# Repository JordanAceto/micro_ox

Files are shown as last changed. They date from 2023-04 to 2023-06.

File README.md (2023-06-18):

# Analog monosynth with digital control path

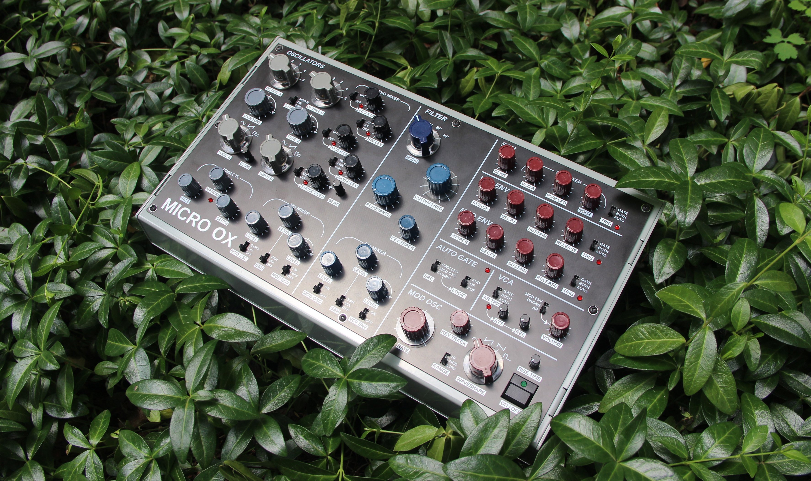
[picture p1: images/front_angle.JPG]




## The idea:
- A stripped down version of the [Josh Oxford Ribbon Synth](https://github.com/JordanAceto/josh_Ox_ribbon_synth) with some changes
- No integrated ribbon controller
- MIDI and CV inputs

## Status:
- 1st prototype is built and under evaluation
- All major features work
- There are a few PCB kludges required for the first board revisions
- Expect minor componenent and code changes as evalutation continues
- The jack panel and body are not started yet
- Documentation is incomplete while the design is in flux, expect some dead links to schematics/etc for now

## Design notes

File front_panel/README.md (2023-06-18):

# front_panel

## micro_ox_front_panel

PCB front
PCB back

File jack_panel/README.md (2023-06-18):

# jack_panel

## jack_panel

PCB front
PCB back

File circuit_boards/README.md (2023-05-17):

# Micro-Ox Circuit Boards

## The system is made up of a few independent PCBs

- VCO board
- VCF/VCA board
- Modulation board
- Power supply and input-output jack board

### These boards are connected to each other via IDC headers
- IDC header pinouts are chosen so it is impossible to plug them in wrong

---

## Each major system component has its own subdirectory with:
- All files needed to edit the schematic and PCB layout with KiCad
- Documentation files needed to build and troubleshoot the circuits

---

## The approximate current draw of the circuitboards is:

| Board | +12V  | -12V  |
| --- | ----- | ----- |
| main VCO  | 70mA  | 60mA  |
| VCF/VCA | 40mA  | 40mA  |
| mod board | 50mA  | 20mA  |
| | | |
| **TOTAL** | 160mA | 120mA |

---

## Some boards may need kludges (small trace cuts/fixes)
- look for a `pcb_kludges` subdirectory in a given circuitboard directory
- if this subdirectory exists, it will include instructions for the kludge in the form of a README file
- if you don't find this directory, assume that the PCB does not require any kludges

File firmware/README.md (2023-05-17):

# Rust Language STM32L412KBU Synthesizer Firmware

## Features
- MIDI receiver listens for MIDI messages via UART
- front panel potentiometers and switches are read by the microcontroller via MUX
- ADSR envelopes are generated digitally
- the Sample & Hold signal is digitized
- White Noise is generated via the built in stm32 hardware RNG and output via PWM
- external DACs generate analog voltages to control various system parameters
- LEDs driven via shift register show the state of the envelope and S&H triggers

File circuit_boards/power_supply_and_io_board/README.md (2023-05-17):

# Micro-Ox Power-Supply and IO board

## [SCHEMATIC](https://github.com/JordanAceto/micro_ox/blob/main/circuit_boards/power_supply_and_io_board/docs/power_supply_and_io_board_schematic.pdf)

Linear +/-12 volt DC power supply and input/output jacks




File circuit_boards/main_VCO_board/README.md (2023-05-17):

# Micro-Ox Dual SSI2130 VCO Board

## [SCHEMATIC](https://github.com/JordanAceto/micro_ox/blob/main/circuit_boards/main_VCO_board/docs/main_VCO_board_schematic.pdf)

## Features
- each VCO has sine, triangle, sawtooth, and variable pulse outputs
- octave switches and fine tuners
- suboctave with sawtooth and variable pulse waves
    - derived from VCO A
    - suboctave is not phase locked to VCO A, has variable beat frequency control
- flexible sync mode
    - VCO B may be soft-synced to VCO A
    - the `MOD B` setting turns off modulation to VCO A, so that only the synced VCO B is modulated
- audio mixer
- transformer/diode based ring modulator
    - XX mode multiplies VCO A with VCO B
    - XY mode multiplies VCO A with the MOD OSC
- PWM control generator
    - PWM control is clamped so the pulse waves can't go beyond about 5% and 95%
    - if overdriving the pulse waves is desired two diodes may be easily removed




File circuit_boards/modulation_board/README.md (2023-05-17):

# Micro-Ox Modulation Board

## [SCHEMATIC](https://github.com/JordanAceto/micro_ox/blob/main/circuit_boards/modulation_board/docs/modulation_board_schematic.pdf)

## Features
- MIDI input listens for a variety of MIDI messages
    - note on/off
    - pitch bend
    - mod-wheel controls the amplitude of the MOD OSC
    - VCF frequency and VCF Q messages
    - master volume
    - more MIDI control may be added in the future (velocity, portamento, sustain, etc)
- Analog Modulation Oscillator
    - SSI2130 based design with good tracking
    - low, medium, and high frequency ranges for LFO and audio rate FM
    - variable key-tracking to follow the MIDI pitch control
    - sine, up-saw, down-saw, and 50% square waves available
    - on/off switch with variable rise/fall time
- two full ADSR envelopes
    - one dedicated to the VCF
    - MOD ENV for modulation purposes
- one AR envelope for the VCA
    - the VCA may be controlled by the dedicated AR, the MOD ENV, or set to drone mode
- sample & hold
    - glide control
    - 3 input mixer
    - s&h mixer output, for use as an auxilliary modulation bus
- flexible auto gate
    - choose either the PWM LFO (from the VCO board), MOD OSC, or a combination of the two as the auto gate source
    - in combination mode the PWM LFO and MOD OSC may be combined via logical operators AND, OR, and XOR
- flexible trigger control for envelopes and sample & hold
    - each component may be triggered by MIDI, external gate signals, the auto gate, or a logical combination




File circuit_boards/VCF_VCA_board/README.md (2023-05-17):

# Micro-Ox VCF/VCA Board

## [SCHEMATIC](https://github.com/JordanAceto/micro_ox/blob/main/circuit_boards/VCF_VCA_board/docs/VCF_VCA_board_schematic.pdf)

## Features
- SSI2140 pole-mixing filter with four outputs
    - 24dB/octave lowpass
    - 12dB/octave lowpass
    - 6dB/octave bandpass
    - 18dB/octave highpass
    - other filter responses are available by changing resistor weights
- Two linear SSI2164 VCAs
    - One dedicated to the envelope
    - One dedicated to the master volume




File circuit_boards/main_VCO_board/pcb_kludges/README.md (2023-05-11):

# VCO Board PCB Kludges

The VCO board needs a kludge to scale and clamp the PWM control voltage for the SSI2130 VCOs, and a kludge to add opamp buffers to the octave switches.

## PWM Scaler Kludge

The PWM circuit on the VCO board is intended to clamp the pulse width modulation so that the width of the pulse wave can get very close to 0% and 100%, but not quite reach. This is to prevent the pulse wave from disappearing when the PWM is overdriven.

The existing clamper circuit clamps the PWM control signal to about [-5.5v, +5.5v]. This is fine for the suboctave pulse wave. But the main VCO A and VCO B pulse waves have a PWM port that is sensitive over [0v, +2.5v], and so it should be clamped to just inside this range.

The network shown below can be kludged in between the PWM output and the SSI2130 PWM input control ports.

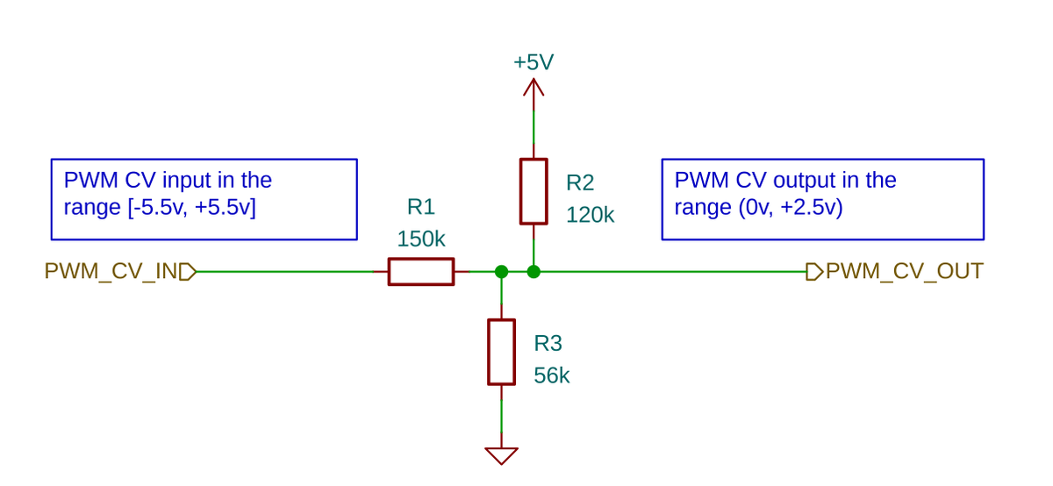
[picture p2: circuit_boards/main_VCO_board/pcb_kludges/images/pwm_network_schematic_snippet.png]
PWM network schematic snippet


This network should be installed so that the Suboctave PWM input still gets the full `[-5.5v, +5.5v]` range. 

A convenient spot to install the kludge is shown below. The input to the network is the trace coming out of the top of `D602`, and the output is the trace exiting the junction of the three kludged resistors.

- The trace going northwards from `D602` is carefully cut underneath the 150k ohm 0805 resistor, and the soldermask is carefully scraped away so that the 150k resistor can be soldered to it. 
- A small section of the soldermask covering the ground plane is scraped away so that the 56k ohm 0805 resistor can be soldered to ground.
- The 120k ohm through-hole resistor is wired to the left end of `D602`, which is connected to the +5v rail.

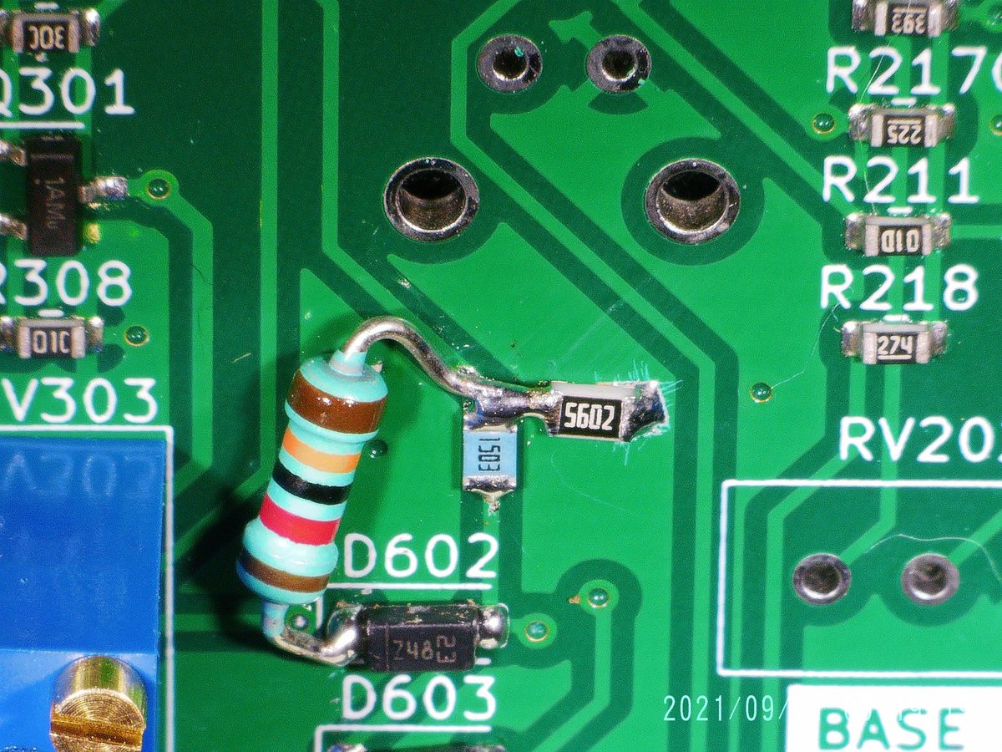
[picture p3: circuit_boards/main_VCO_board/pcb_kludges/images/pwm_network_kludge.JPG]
PWM network image


---

## Octave Switch Buffer Kludge

A single supply, rail-to-rail opamp can be installed "dead bug" style to act as a buffer between the octave switch common pins and the trimmer resistor for calibrating the octave switches. This allows the octave switches to be calibrated.

The PCB traces going from the octave switch common pins must be carefully severed with an exacto knife.

The MCP6002 or similar opamp is powered by the +5v rail. This can be accessed on the left side of R329. The minus supply pin for the opamp may be soldered to the ground plane after scraping away some solder mask.

The buffer may then be constructed according to the images and schematic snippet below.

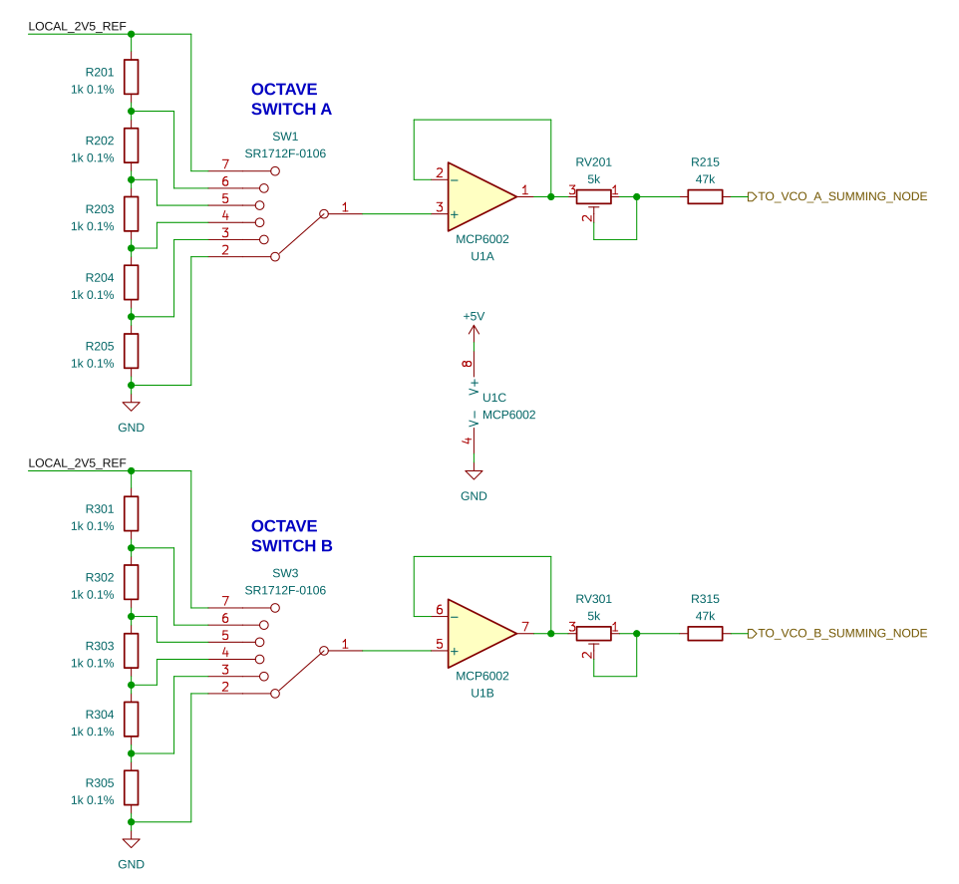
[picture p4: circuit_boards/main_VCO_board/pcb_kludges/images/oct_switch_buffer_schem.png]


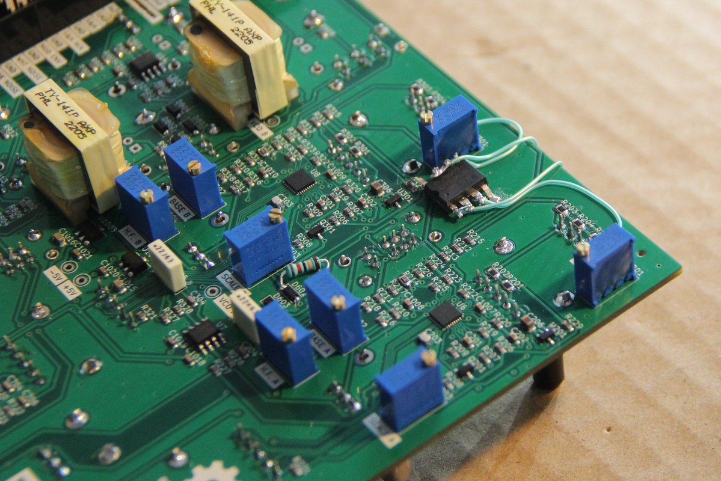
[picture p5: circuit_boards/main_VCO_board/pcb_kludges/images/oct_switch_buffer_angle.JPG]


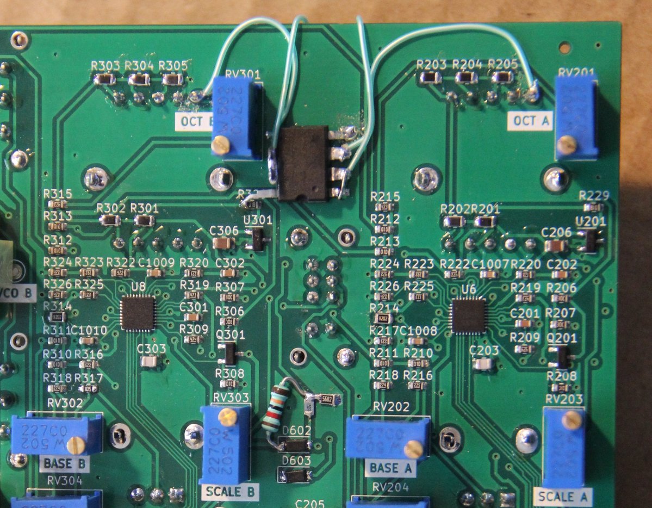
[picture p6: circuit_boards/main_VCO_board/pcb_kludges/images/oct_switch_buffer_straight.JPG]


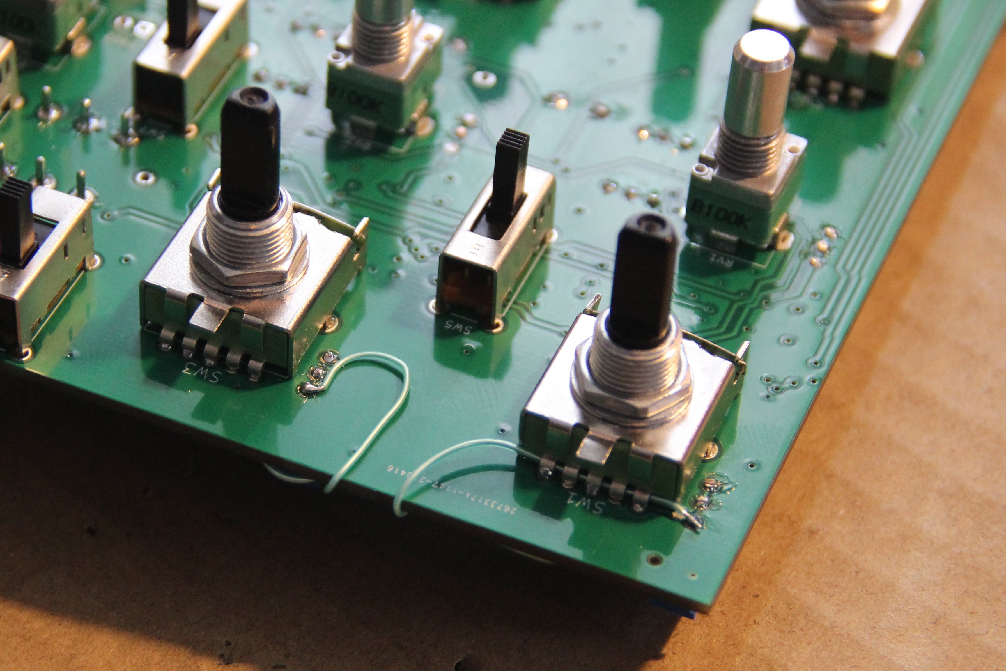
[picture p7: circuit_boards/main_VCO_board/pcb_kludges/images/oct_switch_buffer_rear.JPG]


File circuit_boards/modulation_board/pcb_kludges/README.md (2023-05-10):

# Modulation Board PCB Kludges

The modulation board needs a kludge to ensure that the MODOSC frequency range switch does not short out the +/-5 volt power suppy rails, and a kludge to bias the pink noise.

## MODOSC frequency range switch kludge

### Step 1: cut two traces

In the vicinity of the MODOSC circuitry, carefully cut the two traces as shown with an exacto knife.

The trace on the left in the image supplies -5 volts DC to the MODOOSC frequency range switch, and the trace on the right supplies +5v.

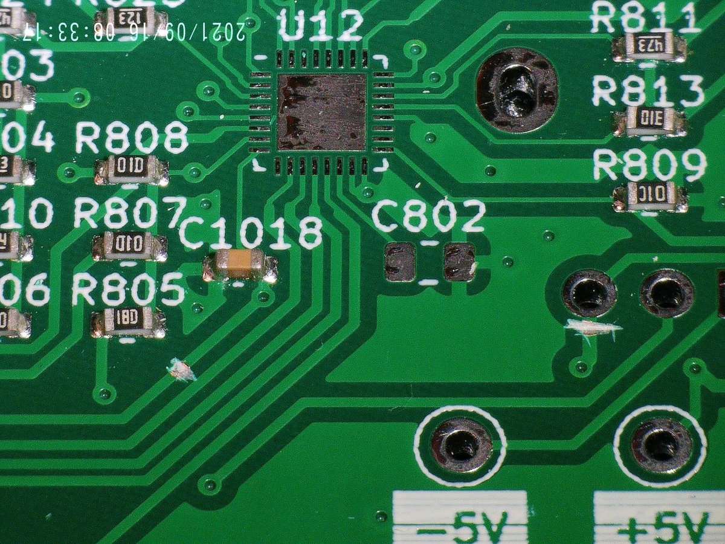
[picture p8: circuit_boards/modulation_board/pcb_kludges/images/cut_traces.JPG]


### Step 2: scrape away solder mask

With the traces severed, carefully scrape away some soldermask to provide for a surface to solder to.

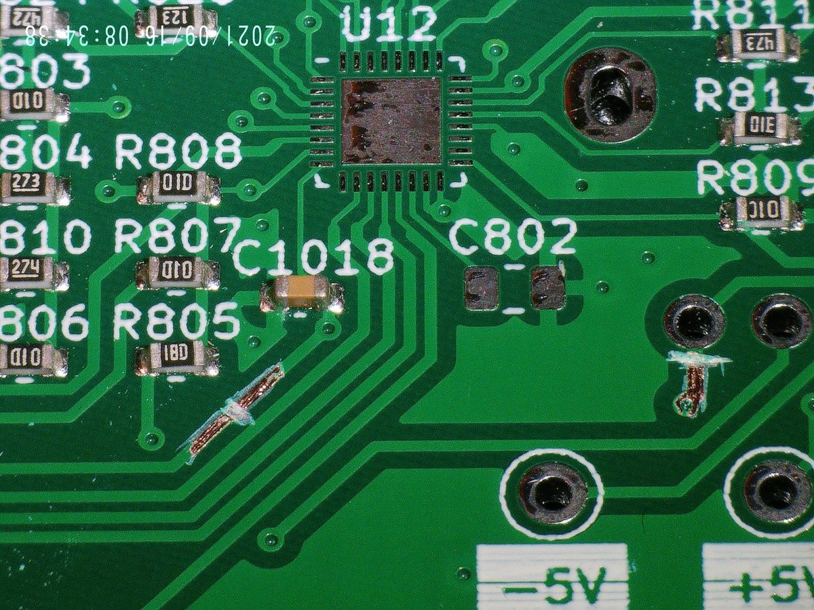
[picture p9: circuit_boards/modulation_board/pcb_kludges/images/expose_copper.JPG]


### Step 3: install two 51k ohm resistors

Solder 51k ohm resistors in series with the cut traces. This puts some impedance in series with the +/-5v lines, so even if the switch momentarily short out no drama will ensue.

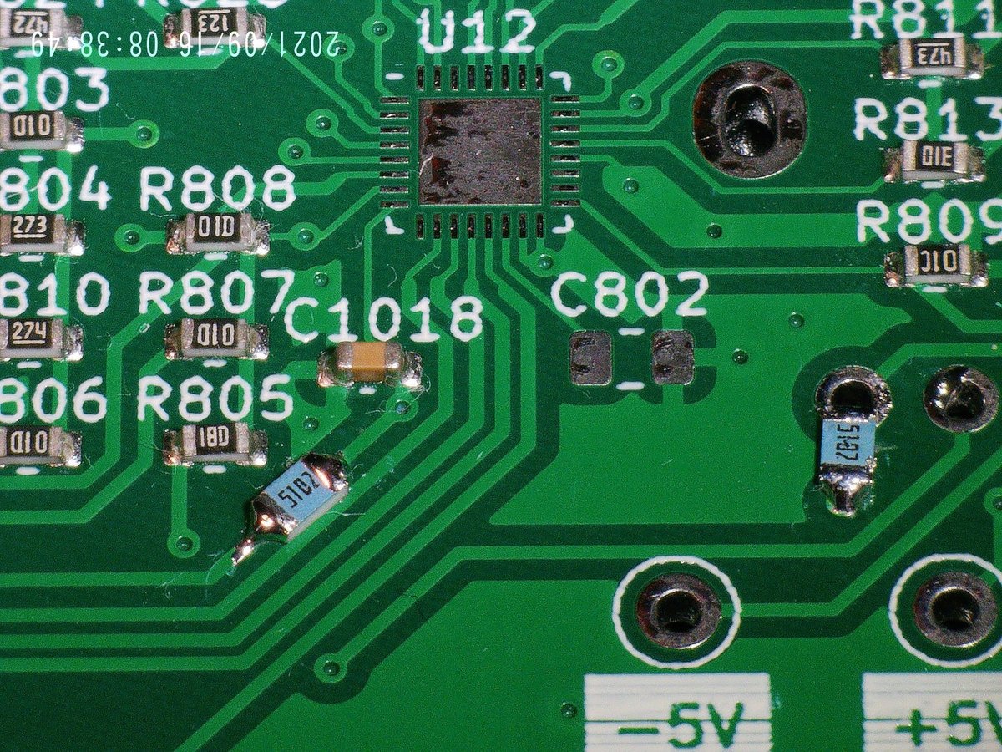
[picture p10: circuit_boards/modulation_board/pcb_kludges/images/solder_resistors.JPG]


---

## Pink Noise bias resistor kludge

Solder a 270k ohm resistor from the -5v rail (available on the left side of R907) and the inverting input of U7A.

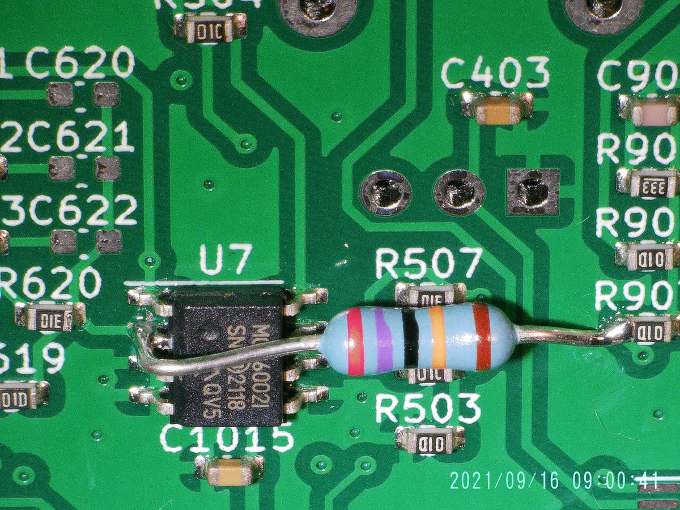
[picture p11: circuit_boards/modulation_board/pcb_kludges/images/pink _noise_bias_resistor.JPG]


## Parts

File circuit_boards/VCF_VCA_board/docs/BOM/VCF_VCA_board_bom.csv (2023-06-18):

# | Reference | Qty | Value | Footprint | DNP
1 | C101 | 1 | 10u BP | Capacitor_THT:C_Radial_D6.3mm_H7.0mm_P2.50mm
2 | C201, C301, C302, C401, C501, C504, C601, C604 | 8 | 100p | Capacitor_SMD:C_0603_1608Metric
3 | C202, C203, C204, C205 | 4 | 1n C0G | Capacitor_SMD:C_0805_2012Metric
4 | C303, C304 | 2 | 220n | Capacitor_THT:C_Rect_L7.0mm_W2.5mm_P5.00mm
5 | C502, C503, C602, C603 | 4 | 1n | Capacitor_SMD:C_0603_1608Metric
6 | C701, C702, C703, C704, C707, C708, C709, C710, C711, C712, C713, C714, C715, C716, C717, C718, C719, C720, C721, C722 | 20 | 100n | Capacitor_SMD:C_0603_1608Metric
7 | C705, C706 | 2 | 10u | Capacitor_THT:CP_Radial_D6.3mm_P2.50mm
8 | D101, D102 | 2 | LED | LED_THT:LED_D5.0mm
9 | J1 | 1 | VCO_BOARD_CON | custom_footprints:8_pin_IDC-Header
10 | J2 | 1 | MOD_BOARD_CON | custom_footprints:34_pin_IDC_header
11 | J3 | 1 | VCF_EXT_CON | custom_footprints:6_pin_IDC-Header
12 | J4 | 1 | power_entry | custom_footprints:10_pin_IDC-Header
13 | R101, R103, R218 | 3 | 1k | Resistor_SMD:R_0603_1608Metric
14 | R102, R209, R313, R314, R401, R402, R403, R404, R405, R406, R408, R409, R505, R605, R702, R703 | 16 | 100k | Resistor_SMD:R_0603_1608Metric
15 | R201, R202, R203, R205, R206, R210, R211, R213, R214, R216 | 10 | 15k | Resistor_SMD:R_0603_1608Metric
16 | R204, R208, R212, R215 | 4 | 200 | Resistor_SMD:R_0603_1608Metric
17 | R207, R508, R608 | 3 | 47k | Resistor_SMD:R_0603_1608Metric
18 | R217, R301, R304, R307, R308, R506, R606 | 7 | 30k | Resistor_SMD:R_0603_1608Metric
19 | R219 | 1 | 20k | Resistor_SMD:R_0603_1608Metric
20 | R220 | 1 | 12k | Resistor_SMD:R_0603_1608Metric
21 | R221 | 1 | 7k5 | Resistor_SMD:R_0603_1608Metric
22 | R302, R303 | 2 | 10k | Resistor_SMD:R_0603_1608Metric
23 | R305, R306, R309, R310 | 4 | DNP | Resistor_SMD:R_0603_1608Metric | DNP
24 | R311, R312 | 2 | 18k | Resistor_SMD:R_0603_1608Metric
25 | R407, R410 | 2 | 22k | Resistor_SMD:R_0603_1608Metric
26 | R501, R601 | 2 | 10M | Resistor_SMD:R_0603_1608Metric
27 | R502, R602 | 2 | 51k | Resistor_SMD:R_0603_1608Metric
28 | R503, R603 | 2 | 4k7 | Resistor_SMD:R_0603_1608Metric
29 | R504, R507, R604, R607 | 4 | 270 | Resistor_SMD:R_0603_1608Metric
30 | R701 | 1 | 2k7 | Resistor_SMD:R_0603_1608Metric
31 | RV1, RV2, RV3, RV4, RV5 | 5 | 100k | custom_footprints:Potentiometer_Alpha_RD901F-40-00D_Single_Vertical
32 | RV6 | 1 | 100k c.d. | custom_footprints:Potentiometer_Alpha_RD901F-40-00D_Single_Vertical
33 | RV201 | 1 | 100k | Potentiometer_THT:Potentiometer_Bourns_3296W_Vertical
34 | RV202 | 1 | 5k | Potentiometer_THT:Potentiometer_Bourns_3296W_Vertical
35 | SW1 | 1 | SR1712F-0204 | custom_footprints:SR1712F_rotary_switch
36 | SW2, SW4 | 2 | E-Switch_EG2201B | custom_footprints:E-Switch_EG2201
37 | SW3 | 1 | E-Switch_EG2301 | custom_footprints:E-Switch_EG2301
38 | TP703 | 1 | GND | TestPoint:TestPoint_Bridge_Pitch7.62mm_Drill1.3mm
39 | U1, U2, U3, U4, U5, U6, U7 | 7 | TL072 | Package_SO:SOIC-8_3.9x4.9mm_P1.27mm
40 | U8 | 1 | SSI2140 | Package_SO:TSSOP-20_4.4x6.5mm_P0.65mm
41 | U9 | 1 | SSI2164 | Package_SO:SOIC-16_3.9x9.9mm_P1.27mm
42 | U707 | 1 | LM4040DBZ-5 | Package_TO_SOT_SMD:SOT-23

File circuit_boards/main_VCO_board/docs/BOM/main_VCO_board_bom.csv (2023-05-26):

# | Reference | Qty | Value | Footprint | DNP
1 | C201, C202, C301, C302 | 4 | 10n | Capacitor_SMD:C_0603_1608Metric
2 | C203, C303 | 2 | 3N9 COG | Capacitor_SMD:C_0805_2012Metric
3 | C204, C304, C402, C403, C404, C501, C502, C603, C703, C705, C801, C802 | 12 | 100p | Capacitor_SMD:C_0603_1608Metric
4 | C205, C305 | 2 | 220n | Capacitor_THT:C_Rect_L7.0mm_W2.0mm_P5.00mm
5 | C206, C306 | 2 | 10u | Capacitor_SMD:C_0805_2012Metric
6 | C401 | 1 | 10u BP | Capacitor_THT:C_Radial_D6.3mm_H7.0mm_P2.50mm
7 | C602 | 1 | 220n | Capacitor_THT:C_Rect_L7.0mm_W2.5mm_P5.00mm
8 | C701, C704, C803, C901 | 4 | 10p | Capacitor_SMD:C_0603_1608Metric
9 | C702 | 1 | 1u | Capacitor_THT:C_Rect_L7.0mm_W2.5mm_P5.00mm
10 | C706 | 1 | 1n | Capacitor_SMD:C_0603_1608Metric
11 | C1001, C1002, C1003, C1004, C1007, C1008, C1009, C1010, C1011, C1012, C1013, C1014, C1017, C1018, C1019, C1020, C1021, C1022, C1023, C1024, C1025, C1027, C1028, C1029, C1030, C1031, C1032, C1033, C1034, C1035, C1036 | 31 | 100n | Capacitor_SMD:C_0603_1608Metric
12 | C1005, C1006 | 2 | 10u | Capacitor_THT:CP_Radial_D6.3mm_P2.50mm
13 | C1015, C1016 | 2 | 470n | Capacitor_SMD:C_0805_2012Metric
14 | D601 | 1 | LED | LED_THT:LED_D3.0mm
15 | D602, D603, D801, D802, D803, D804 | 6 | BAT48ZFILM | Diode_SMD:D_SOD-123
16 | D701 | 1 | 1N4148W | Diode_SMD:D_SOD-123
17 | D901, D902, D903, D904, D905 | 5 | XLMDK65D | LED_THT:LED_D3.0mm
18 | J1 | 1 | VCF_BOARD_CON | custom_footprints:8_pin_IDC-Header
19 | J2 | 1 | MOD_BOARD_CON | custom_footprints:40_pin_IDC_header
20 | J3 | 1 | VCO_EXT_CON | custom_footprints:12_pin_IDC_header
21 | J4 | 1 | power_entry | custom_footprints:10_pin_IDC-Header
22 | Q201, Q301, Q601 | 3 | MMBT3904 | Package_TO_SOT_SMD:SOT-23
23 | Q401 | 1 | 2N7002 | Package_TO_SOT_SMD:SOT-23
24 | R101, R102, R210, R211, R212, R213, R310, R311, R312, R313, R403, R405, R501, R502, R503, R504, R505, R506, R601, R606, R609, R611, R612, R615, R701, R706, R709, R710, R712, R713, R714, R716, R717, R719, R723, R801, R802, R807, R901, R902, R903, R904, R905 | 43 | 100k | Resistor_SMD:R_0603_1608Metric
25 | R201, R202, R203, R204, R205, R301, R302, R303, R304, R305 | 10 | 1k 0.1% | Resistor_SMD:R_0805_2012Metric
26 | R206, R207, R227, R306, R307, R327, R407, R408, R409 | 9 | 20k | Resistor_SMD:R_0603_1608Metric
27 | R208, R308, R406, R610, R718, R906, R907, R1003, R1004 | 9 | 10k | Resistor_SMD:R_0603_1608Metric
28 | R209, R309 | 2 | 470k | Resistor_SMD:R_0603_1608Metric
29 | R214, R314 | 2 | 82k | Resistor_SMD:R_0603_1608Metric
30 | R215, R219, R221, R315, R319, R321 | 6 | 47k | Resistor_SMD:R_0603_1608Metric
31 | R216, R316 | 2 | 2M2 | Resistor_SMD:R_0603_1608Metric
32 | R217, R317, R608, R705, R708, R808 | 6 | 1M | Resistor_SMD:R_0603_1608Metric
33 | R218, R318, R602 | 3 | 270k | Resistor_SMD:R_0603_1608Metric
34 | R220, R320 | 2 | 270 | Resistor_SMD:R_0603_1608Metric
35 | R222, R224, R226, R322, R324, R326, R1002 | 7 | 4k7 | Resistor_SMD:R_0603_1608Metric
36 | R223, R323 | 2 | 3k9 | Resistor_SMD:R_0603_1608Metric
37 | R225, R325, R908, R909, R910, R912 | 6 | 12k | Resistor_SMD:R_0603_1608Metric
38 | R228, R328 | 2 | 56k | Resistor_SMD:R_0603_1608Metric
39 | R229, R329, R616, R707 | 4 | 1k | Resistor_SMD:R_0603_1608Metric
40 | R401 | 1 | 200k | Resistor_SMD:R_0603_1608Metric
41 | R402, R803, R804 | 3 | 33k | Resistor_SMD:R_0603_1608Metric
42 | R404, R605 | 2 | 100 | Resistor_SMD:R_0603_1608Metric
43 | R607 | 1 | 120k | Resistor_SMD:R_0603_1608Metric
44 | R613 | 1 | 30k | Resistor_SMD:R_0603_1608Metric
45 | R702 | 1 | 220k | Resistor_SMD:R_0603_1608Metric
46 | R703, R805, R806 | 3 | 330 | Resistor_SMD:R_0603_1608Metric
47 | R704, R711 | 2 | 68k | Resistor_SMD:R_0603_1608Metric
48 | R715 | 1 | 15k | Resistor_SMD:R_0603_1608Metric
49 | R720 | 1 | 10M | Resistor_SMD:R_0603_1608Metric
50 | R721 | 1 | 2k2 | Resistor_SMD:R_0603_1608Metric
51 | R722 | 1 | 1k8 | Resistor_SMD:R_0603_1608Metric
52 | R911 | 1 | 5k6 | Resistor_SMD:R_0603_1608Metric
53 | RV1, RV2, RV5, RV6, RV7, RV8, RV9, RV10, RV11, RV13, RV14 | 11 | 100k | custom_footprints:Potentiometer_Alpha_RD901F-40-00D_Single_Vertical
54 | RV3 | 1 | 100k | custom_footprints:Bourns_PTV09
55 | RV4 | 1 | 100k A | custom_footprints:Potentiometer_Alpha_RD901F-40-00D_Single_Vertical
56 | RV12 | 1 | 100k | Potentiometer_THT:Potentiometer_Alpha_RD901F-40-00D_Single_Vertical
57 | RV15 | 1 | 100k c.d. | custom_footprints:Potentiometer_Alpha_RD901F-40-00D_Single_Vertical
58 | RV201, RV202, RV203, RV204, RV301, RV302, RV303, RV304 | 8 | 5k | Potentiometer_THT:Potentiometer_Bourns_3296W_Vertical
59 | RV701, RV703 | 2 | 50k | Potentiometer_THT:Potentiometer_Bourns_3296W_Vertical
60 | SW1, SW3 | 2 | SR1712F-0106 | custom_footprints:SR1712F_rotary_switch
61 | SW2, SW4 | 2 | SR1712F-0204 | custom_footprints:SR1712F_rotary_switch
62 | SW5, SW8, SW9, SW10, SW11, SW12 | 6 | E-Switch_EG2301B | custom_footprints:E-Switch_EG2301
63 | SW6, SW7 | 2 | E-Switch_EG2201B | custom_footprints:E-Switch_EG2201
64 | SW13 | 1 | E-Switch_EG2301 | custom_footprints:E-Switch_EG2301
65 | TP201, TP301 | 2 | VCO | TestPoint:TestPoint_Keystone_5000-5004_Miniature
66 | TP701 | 1 | anim_LFO | TestPoint:TestPoint_Keystone_5000-5004_Miniature
67 | TP702 | 1 | suboct_init | TestPoint:TestPoint_Keystone_5000-5004_Miniature
68 | TP703 | 1 | suboct_fin | TestPoint:TestPoint_Keystone_5000-5004_Miniature
69 | TP801 | 1 | ring_mod | TestPoint:TestPoint_Keystone_5000-5004_Miniature
70 | TP901 | 1 | audio_mix | TestPoint:TestPoint_Keystone_5000-5004_Miniature
71 | TP1001 | 1 | V+ | TestPoint:TestPoint_Keystone_5000-5004_Miniature
72 | TP1002 | 1 | V- | TestPoint:TestPoint_Keystone_5000-5004_Miniature
73 | TP1003 | 1 | GND | TestPoint:TestPoint_Bridge_Pitch7.62mm_Drill1.3mm
74 | TP1004 | 1 | +5 | TestPoint:TestPoint_Keystone_5000-5004_Miniature
75 | TP1005 | 1 | -5 | TestPoint:TestPoint_Keystone_5000-5004_Miniature
76 | TP1006 | 1 | +5_REF | TestPoint:TestPoint_Keystone_5000-5004_Miniature
77 | TP1008 | 1 | -5_REF | TestPoint:TestPoint_Keystone_5000-5004_Miniature
78 | TR801, TR802 | 2 | Triad_TY_141P | custom_footprints:Triad_TY-141P
79 | U1, U2, U3, U5, U7, U10, U11, U14, U15 | 9 | TL072 | Package_SO:SOIC-8_3.9x4.9mm_P1.27mm
80 | U4 | 1 | LM311 | Package_SO:SOIC-8_3.9x4.9mm_P1.27mm
81 | U6, U8 | 2 | SSI2130 | Package_DFN_QFN:QFN-32-1EP_4x4mm_P0.4mm_EP2.9x2.9mm
82 | U9 | 1 | 4013 | Package_SO:SOIC-14_3.9x8.7mm_P1.27mm
83 | U12 | 1 | LM324 | Package_SO:SOIC-14_3.9x8.7mm_P1.27mm
84 | U13 | 1 | NE5532 | Package_SO:SOIC-8_3.9x4.9mm_P1.27mm
85 | U201, U301 | 2 | LM4040C-2.5 | Package_TO_SOT_SMD:SOT-23
86 | U1002 | 1 | L78L05_SOT89 | Package_TO_SOT_SMD:SOT-89-3
87 | U1003 | 1 | L79L05_SOT89 | Package_TO_SOT_SMD:SOT-89-3
88 | U1005 | 1 | LM4040DBZ-5 | Package_TO_SOT_SMD:SOT-23

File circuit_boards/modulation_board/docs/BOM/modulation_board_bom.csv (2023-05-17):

# | Reference | Qty | Value | Footprint | DNP
1 | C301, C304, C305, C306, C309, C311, C401, C402, C403, C404, C405, C406, C407, C408, C409, C410, C411, C412, C413, C414, C501, C602, C609, C612, C613, C616, C618, C619, C701, C1005, C1006, C1008, C1009, C1010, C1011, C1012, C1013, C1014, C1015, C1016, C1017, C1018 | 42 | 100n | Capacitor_SMD:C_0603_1608Metric
2 | C302, C303 | 2 | 4p3 | Capacitor_SMD:C_0603_1608Metric
3 | C307, C601, C614 | 3 | 1u | Capacitor_SMD:C_0805_2012Metric
4 | C308, C310, C604, C610, C624, C805 | 6 | 10u | Capacitor_SMD:C_0805_2012Metric
5 | C603, C611, C615, C617, C801 | 5 | 10n | Capacitor_SMD:C_0603_1608Metric
6 | C605, C606, C607, C608 | 4 | 1n | Capacitor_SMD:C_0603_1608Metric
7 | C620 | 1 | 820p | Capacitor_SMD:C_0603_1608Metric
8 | C621 | 1 | 2n2 | Capacitor_SMD:C_0603_1608Metric
9 | C622 | 1 | 5n6 | Capacitor_SMD:C_0603_1608Metric
10 | C802 | 1 | 47n COG | Capacitor_SMD:C_0805_2012Metric
11 | C803, C804, C901, C902, C903 | 5 | 100p | Capacitor_SMD:C_0603_1608Metric
12 | C1001, C1002 | 2 | 10u | Capacitor_THT:CP_Radial_D6.3mm_P2.50mm
13 | C1003, C1004 | 2 | 470n | Capacitor_SMD:C_0805_2012Metric
14 | C1007 | 1 | 2u2 | Capacitor_SMD:C_0805_2012Metric
15 | D301, D501 | 2 | 1N4148W | Diode_SMD:D_SOD-123
16 | D701, D702, D703, D704, D705 | 5 | LED | LED_THT:LED_D3.0mm
17 | FB301, FB302, FB303, FB304 | 4 | 1k@100MHz | Inductor_SMD:L_0805_2012Metric
18 | FB1001, FB1002 | 2 | 100R @ 100MHz | Inductor_SMD:L_0805_2012Metric
19 | J1 | 1 | MOD_BOARD_EXT_CON | custom_footprints:16_pin_IDC_header
20 | J2 | 1 | VCO_BOARD_CON | custom_footprints:40_pin_IDC_header
21 | J3 | 1 | VCF_BOARD_CON | custom_footprints:34_pin_IDC_header
22 | J4 | 1 | power_entry | custom_footprints:10_pin_IDC-Header
23 | J301 | 1 | SWD_header | Connector_PinHeader_2.54mm:PinHeader_1x04_P2.54mm_Vertical
24 | Q501, Q801 | 2 | MMBT3904 | Package_TO_SOT_SMD:SOT-23
25 | R301, R304, R307 | 3 | 220 | Resistor_SMD:R_0603_1608Metric
26 | R302, R303, R308, R309, R402, R504, R505, R611, R615, R624, R809, R815, R822, R825, R903 | 15 | 10k | Resistor_SMD:R_0603_1608Metric
27 | R305 | 1 | 22 | Resistor_SMD:R_0603_1608Metric
28 | R306 | 1 | 10 | Resistor_SMD:R_0603_1608Metric
29 | R401 | 1 | 5k6 | Resistor_SMD:R_0603_1608Metric
30 | R502, R503, R619, R622, R803, R807, R808, R814, R816, R818, R901, R902, R904, R905, R906, R907, R908 | 17 | 100k | Resistor_SMD:R_0603_1608Metric
31 | R507, R620, R813 | 3 | 1M | Resistor_SMD:R_0603_1608Metric
32 | R601, R602, R603, R604, R605, R606, R607, R618, R828 | 9 | 1k | Resistor_SMD:R_0603_1608Metric
33 | R608 | 1 | 820 | Resistor_SMD:R_0603_1608Metric
34 | R609, R820 | 2 | 3k9 | Resistor_SMD:R_0603_1608Metric
35 | R610, R614, R801, R802, R826 | 5 | 20k | Resistor_SMD:R_0603_1608Metric
36 | R612 | 1 | 68k | Resistor_SMD:R_0603_1608Metric
37 | R613, R616, R811 | 3 | 47k | Resistor_SMD:R_0603_1608Metric
38 | R617 | 1 | 6k8 | Resistor_SMD:R_0603_1608Metric
39 | R621 | 1 | 18k | Resistor_SMD:R_0603_1608Metric
40 | R623 | 1 | 330k | Resistor_SMD:R_0603_1608Metric
41 | R701, R702, R703, R704, R705, R821, R824 | 7 | 4k7 | Resistor_SMD:R_0603_1608Metric
42 | R804 | 1 | 27k | Resistor_SMD:R_0603_1608Metric
43 | R805 | 1 | 150k | Resistor_SMD:R_0603_1608Metric
44 | R806 | 1 | 51k | Resistor_SMD:R_0603_1608Metric
45 | R810 | 1 | 270k | Resistor_SMD:R_0603_1608Metric
46 | R812 | 1 | 270 | Resistor_SMD:R_0603_1608Metric
47 | R817, R819 | 2 | 200k | Resistor_SMD:R_0603_1608Metric
48 | R823 | 1 | 12k | Resistor_SMD:R_0603_1608Metric
49 | R827 | 1 | 56k | Resistor_SMD:R_0603_1608Metric
50 | R909 | 1 | 33k | Resistor_SMD:R_0603_1608Metric
51 | RV401, RV402, RV403, RV404, RV405, RV406, RV407, RV408, RV412, RV603, RV801, RV802, RV901, RV902, RV903 | 15 | 100k | custom_footprints:Potentiometer_Alpha_RD901F-40-00D_Single_Vertical
52 | RV409, RV410, RV411 | 3 | 100k | custom_footprints:Bourns_PTV09
53 | RV601, RV602, RV803, RV804, RV805 | 5 | 5k | Potentiometer_THT:Potentiometer_Bourns_3296W_Vertical
54 | SW301 | 1 | 5511M12 | custom_footprints:E_Switch_5511M12
55 | SW501, SW502, SW503, SW504, SW505, SW506, SW507, SW801 | 8 | E-Switch_EG2301B | custom_footprints:E-Switch_EG2301
56 | SW802 | 1 | SR1712F-0204 | custom_footprints:SR1712F_rotary_switch
57 | TP301 | 1 | debug_pin | TestPoint:TestPoint_Keystone_5000-5004_Miniature
58 | TP601 | 1 | DAC_Vref | TestPoint:TestPoint_Keystone_5000-5004_Miniature
59 | TP602 | 1 | PITCH_CV | TestPoint:TestPoint_Keystone_5000-5004_Miniature
60 | TP603 | 1 | S&H_CV | TestPoint:TestPoint_Keystone_5000-5004_Miniature
61 | TP801 | 1 | MODOSC_Vref | TestPoint:TestPoint_Keystone_5000-5004_Miniature
62 | TP802 | 1 | MODOSC | TestPoint:TestPoint_Keystone_5000-5004_Miniature
63 | TP1001 | 1 | V+ | TestPoint:TestPoint_Keystone_5000-5004_Miniature
64 | TP1002 | 1 | V- | TestPoint:TestPoint_Keystone_5000-5004_Miniature
65 | TP1003 | 1 | GND | TestPoint:TestPoint_Bridge_Pitch7.62mm_Drill1.3mm
66 | TP1004 | 1 | +5v | TestPoint:TestPoint_Keystone_5000-5004_Miniature
67 | TP1005 | 1 | -5v | TestPoint:TestPoint_Keystone_5000-5004_Miniature
68 | TP1006 | 1 | 3v3 | TestPoint:TestPoint_Keystone_5000-5004_Miniature
69 | U1 | 1 | STM32L412K8Ux | Package_DFN_QFN:QFN-32-1EP_5x5mm_P0.5mm_EP3.45x3.45mm
70 | U2 | 1 | VO0600T | Package_SO:SOIC-8_3.9x4.9mm_P1.27mm
71 | U3 | 1 | SN74LV1T34DBV | Package_TO_SOT_SMD:SOT-23-5
72 | U4, U801 | 2 | LM4040C-2.5 | Package_TO_SOT_SMD:SOT-23
73 | U5, U6 | 2 | 74HC4067PW | Package_SO:TSSOP-24_4.4x7.8mm_P0.65mm
74 | U7, U15 | 2 | MCP6002-xSN | Package_SO:SOIC-8_3.9x4.9mm_P1.27mm
75 | U8 | 1 | DAC8162xDGSx | Package_SO:VSSOP-10_3x3mm_P0.5mm
76 | U9 | 1 | DAC128S085CIMT | Package_SO:TSSOP-16_4.4x5mm_P0.65mm
77 | U10, U13, U14 | 3 | TL072 | Package_SO:SOIC-8_3.9x4.9mm_P1.27mm
78 | U11 | 1 | 74HC595 | Package_SO:SOIC-16_3.9x9.9mm_P1.27mm
79 | U12 | 1 | SSI2130 | Package_DFN_QFN:QFN-32-1EP_4x4mm_P0.4mm_EP2.9x2.9mm
80 | U1001 | 1 | L78L05_SOT89 | Package_TO_SOT_SMD:SOT-89-3
81 | U1002 | 1 | L79L05_SOT89 | Package_TO_SOT_SMD:SOT-89-3
82 | U1003 | 1 | L78L33_SOT89 | Package_TO_SOT_SMD:SOT-89-3
83 | Y301 | 1 | 32_768KHZ | Crystal:Crystal_SMD_MicroCrystal_CC7V-T1A-2Pin_3.2x1.5mm

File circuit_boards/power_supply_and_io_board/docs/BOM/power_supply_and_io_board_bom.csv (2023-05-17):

# | Reference | Qty | Value | Footprint | DNP
1 | C1, C2, C3, C4 | 4 | 2200u | Capacitor_THT:CP_Radial_D18.0mm_P7.50mm
2 | C5, C6, C7, C8 | 4 | 100n | Capacitor_SMD:C_0805_2012Metric
3 | C9, C10 | 2 | 10u | Capacitor_THT:CP_Radial_D6.3mm_P2.50mm
4 | D1, D2, D3, D4, D5, D6, D7, D8 | 8 | 1N4002 | Diode_THT:D_DO-41_SOD81_P10.16mm_Horizontal
5 | HS1, HS2 | 2 | AAVID_TV-5G | Heatsink:Heatsink_AAVID_TV5G_TO220_Horizontal
6 | J1, J2, J3, J4, J5, J6 | 6 | PJ302M | custom_footprints:PJ302M
7 | J7, J8 | 2 | CUI_SDF-50J | custom_footprints:CUI_SDF-50J
8 | J9 | 1 | NRJ6HM-1 | custom_footprints:Jack_6.35mm_Neutrik_NRJ6HM-1_Horizontal
9 | J10 | 1 | VCO_EXT_CON | custom_footprints:12_pin_IDC_header
10 | J11 | 1 | VCF_EXT_CON | custom_footprints:6_pin_IDC-Header
11 | J12 | 1 | MOD_BOARD_EXT_CON | custom_footprints:16_pin_IDC_header
12 | J13, J14, J15 | 3 | power_out | custom_footprints:10_pin_IDC-Header
13 | J16 | 1 | Mini-Fit_Jr_5566 | Connector_Molex:Molex_Mini-Fit_Jr_5566-04A_2x02_P4.20mm_Vertical
14 | M1 | 1 | keystone_7792 | custom_footprints:keystone_7792
15 | R1, R2 | 2 | 240 | Resistor_SMD:R_0805_2012Metric
16 | RV1, RV2 | 2 | 5k | Potentiometer_THT:Potentiometer_Bourns_3296W_Vertical
17 | TP1 | 1 | V+ | TestPoint:TestPoint_Keystone_5000-5004_Miniature
18 | TP2 | 1 | V- | TestPoint:TestPoint_Keystone_5000-5004_Miniature
19 | TP3 | 1 | GND | TestPoint:TestPoint_Bridge_Pitch7.62mm_Drill1.3mm
20 | U1 | 1 | LM317_TO-220 | Package_TO_SOT_THT:TO-220-3_Horizontal_TabDown
21 | U2 | 1 | LM337_TO220 | Package_TO_SOT_THT:TO-220-3_Horizontal_TabDown

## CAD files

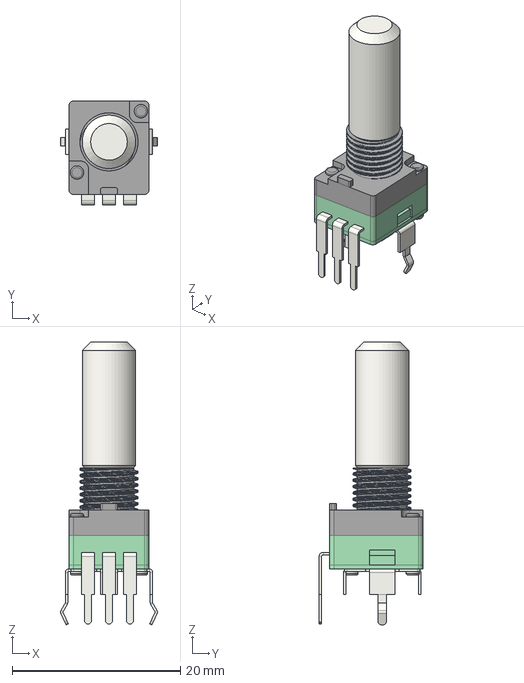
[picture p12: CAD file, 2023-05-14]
circuit_boards/modulation_board/kicad_7/custom_footprints/ALPHA-RD901F-40.step
11.5 x 12.4 x 33.6 mm

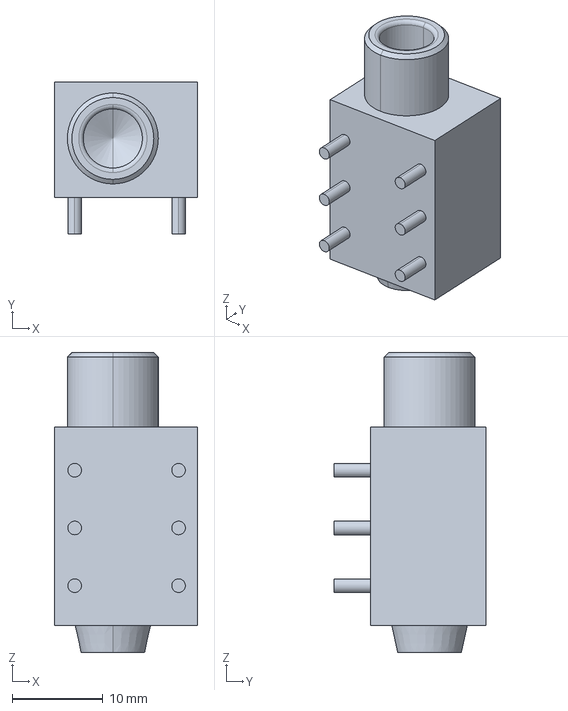
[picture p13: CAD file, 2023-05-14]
circuit_boards/power_supply_and_io_board/kicad_7/custom_footprints/nrj6hm-1.stp
15.8 x 16.7 x 33.0 mm

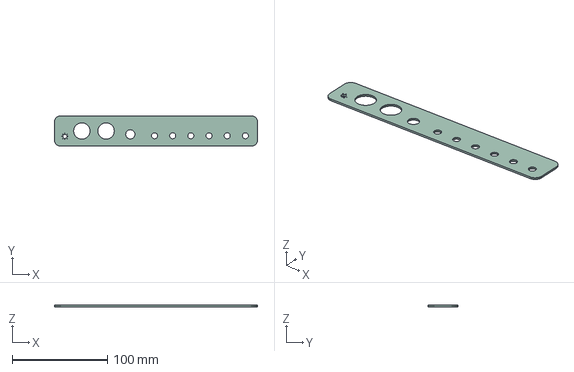
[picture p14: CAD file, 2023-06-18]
jack_panel/docs/3D/jack_panel.step
212.9 x 31.8 x 1.58 mm

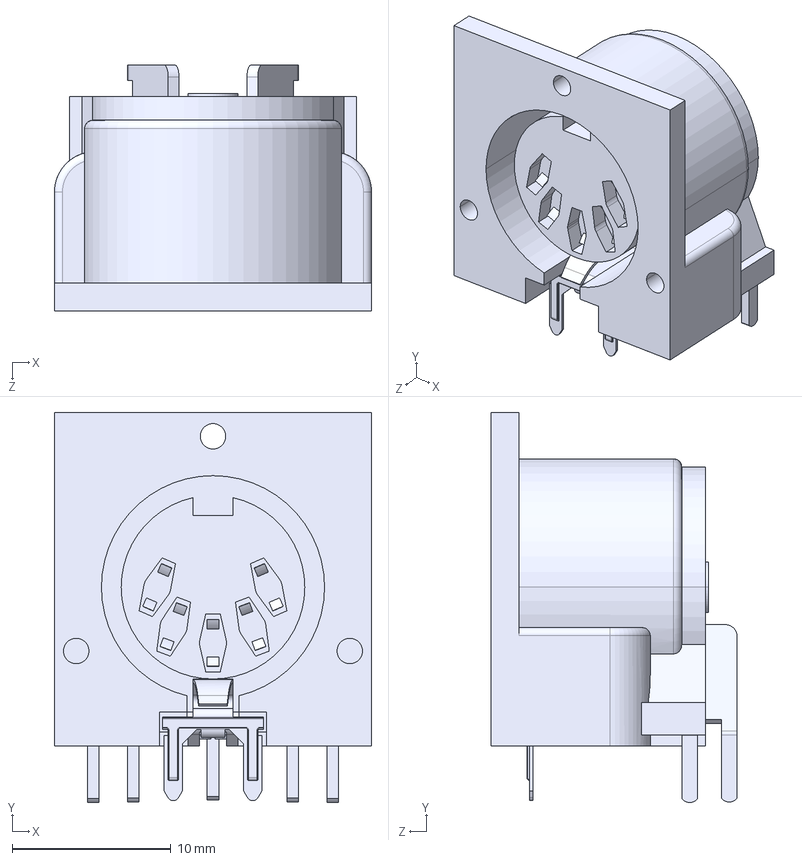
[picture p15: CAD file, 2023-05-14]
circuit_boards/power_supply_and_io_board/kicad_7/custom_footprints/57PC5F.STEP
20.0 x 24.5 x 15.5 mm

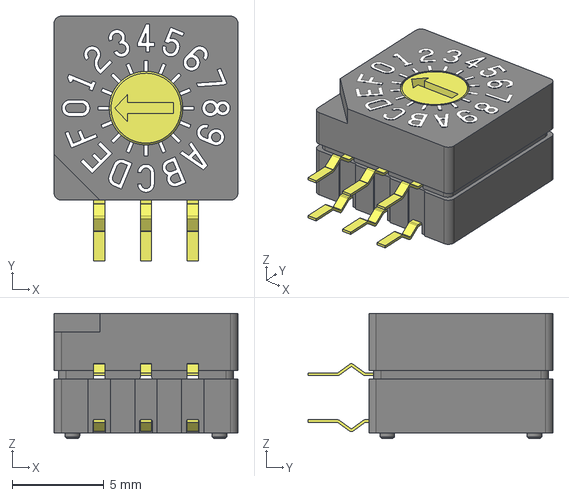
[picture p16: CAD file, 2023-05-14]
circuit_boards/power_supply_and_io_board/kicad_7/custom_footprints/SD-1011.stp
10.0 x 13.3 x 6.82 mm
SD-1_di
SD-1011_b

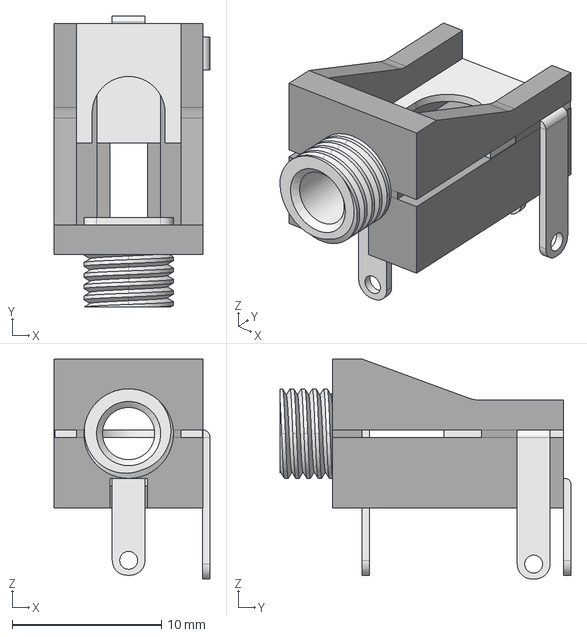
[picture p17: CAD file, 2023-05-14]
circuit_boards/power_supply_and_io_board/kicad_7/custom_footprints/PJ302M.step
10.4 x 19.5 x 14.8 mm

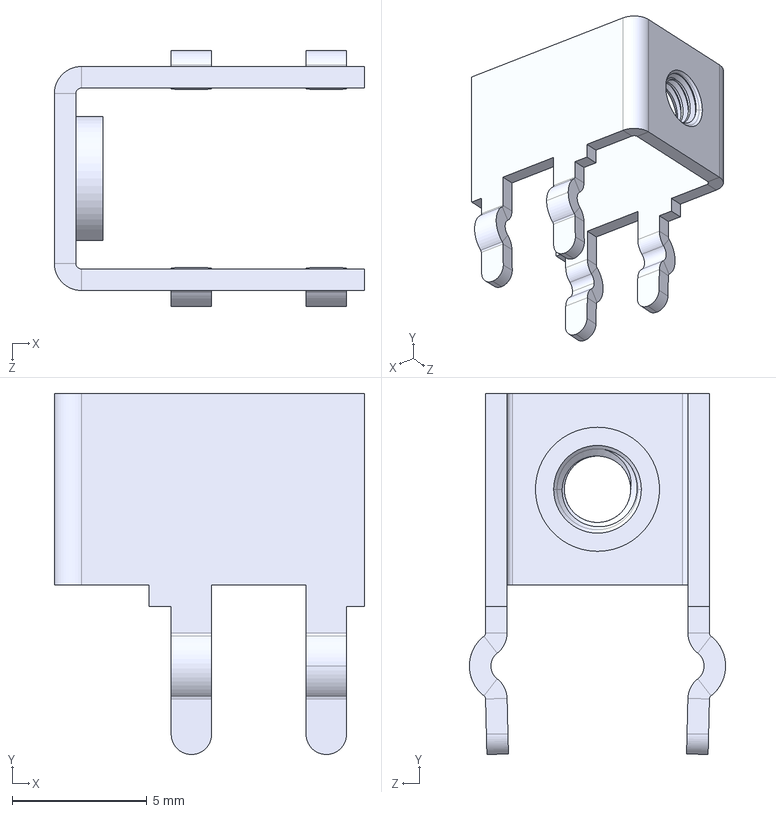
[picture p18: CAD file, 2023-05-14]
circuit_boards/power_supply_and_io_board/kicad_7/custom_footprints/keystone_779x.STEP
11.5 x 13.4 x 9.50 mm

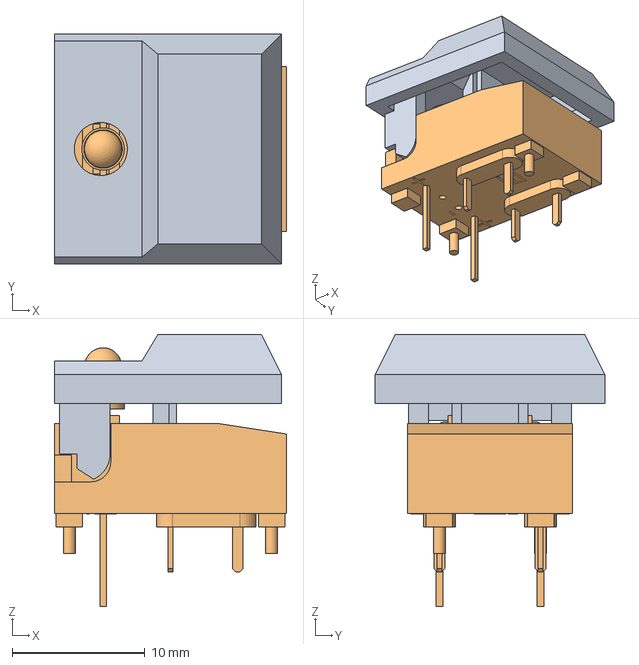
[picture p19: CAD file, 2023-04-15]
circuit_boards/power_supply_and_io_board/kicad_7/custom_footprints/5511MBLKxxx.stp
17.5 x 17.3 x 20.5 mm

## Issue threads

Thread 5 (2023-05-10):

Suboct animation LFO can run to the rails at very low frequencies

JordanAceto, 2023-05-10:
On the VCO board the Suboctave is generated by dividing VCO 1 down by one octave. Both sawtooth and pulse waves are available, and the divided signal is fed through an Electronotes style sawtooth animator circuit to allow it to beat against VCO 1. It sounds better to me this way, I don't like suboctave circuits that have a static relationship with the original waveshape.

The animator circuit uses a common triangle/square opamp LFO to provide the animation. When this LFO is set to very slow speeds it stops working and eventually runs towards the negative power supply rail and stays there. This adds a large offset to the Suboct sawtooth output and puts the pulse wave output into a region where it is just DC for most of the range of the PWM control.

Investigate ways to make this LFO nice and slow, but not so slow that it rails out. This might involve reducing the value of the resistor going to the integrator, changing the value of the integrator cap, or a combination of things.

JordanAceto, 2023-05-26:
Fixed by changing integrator capacitor and input resistor.

Closed 2023-05-26.

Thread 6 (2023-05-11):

VCO octave switches need buffers

JordanAceto, 2023-05-11:
On the main VCO board the VCOs have 6 position octave switches that select a voltage from a string of resistors. This voltage is fed through a trimmer and resistor to the exponential frequency summing node of the SSI2130 VCO chips.

However, because the impedance seen by the resistor string changes depending on which position the switch is set to, it is impossible to calibrate the switch to select in-tune octaves over the full 6 position range.

A simple opamp buffer between the common pin of the switches and the trimmer should fix this.

In the meantime a small daughter board can be built and kludged on to the VCO pcb.

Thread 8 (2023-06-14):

Rotary switches are Break Before Make, user can set them to in-between postions

JordanAceto, 2023-06-14:
The rotary switches used for VCO octave select, VCO wave, VCF filter type, and MODOSC wave are all alpha SR1712F-xxxx  break-before-make. These have a fairly light touch, and you can lodge them in in-between settings pretty easily.

For the VCO wave, VCF type, and MODOSC wave this means that the sound goes away when stuck in-between. For the VCO octave switches this means the VCOs go crazy with an ill-defined pitch input and warble all over.

This is workable if the user is reasonably careful when setting the switches, but it would be nice if they didn't have to worry about this. IMO it is more of an issue with the VCO octave switches.

Consider alternative approaches to the switches. The alpha switches were chosen for their price and availability. I do not know of a reliable source of these switches with Make Before Break action, but maybe they exist. At this point I'd rather not change the switch footprint itself.

Perhaps the physical switches could drive analog switches which are set to always be in a defined state. Maybe the physical switches could even be read by the microcontroller which then drives analog switches.

Also note that the VCO octave switches are 6 position, while the other switches are all 4 position. Six positions is cool and all for the octave select, but really four octaves would probably be fine too if you decide to make them all 4 positions. Many popular synths have only 3 or 4 settings for the octave switch. This would require a front panel respin as well.

No hurry to make big changes, but consider this is food for thought.

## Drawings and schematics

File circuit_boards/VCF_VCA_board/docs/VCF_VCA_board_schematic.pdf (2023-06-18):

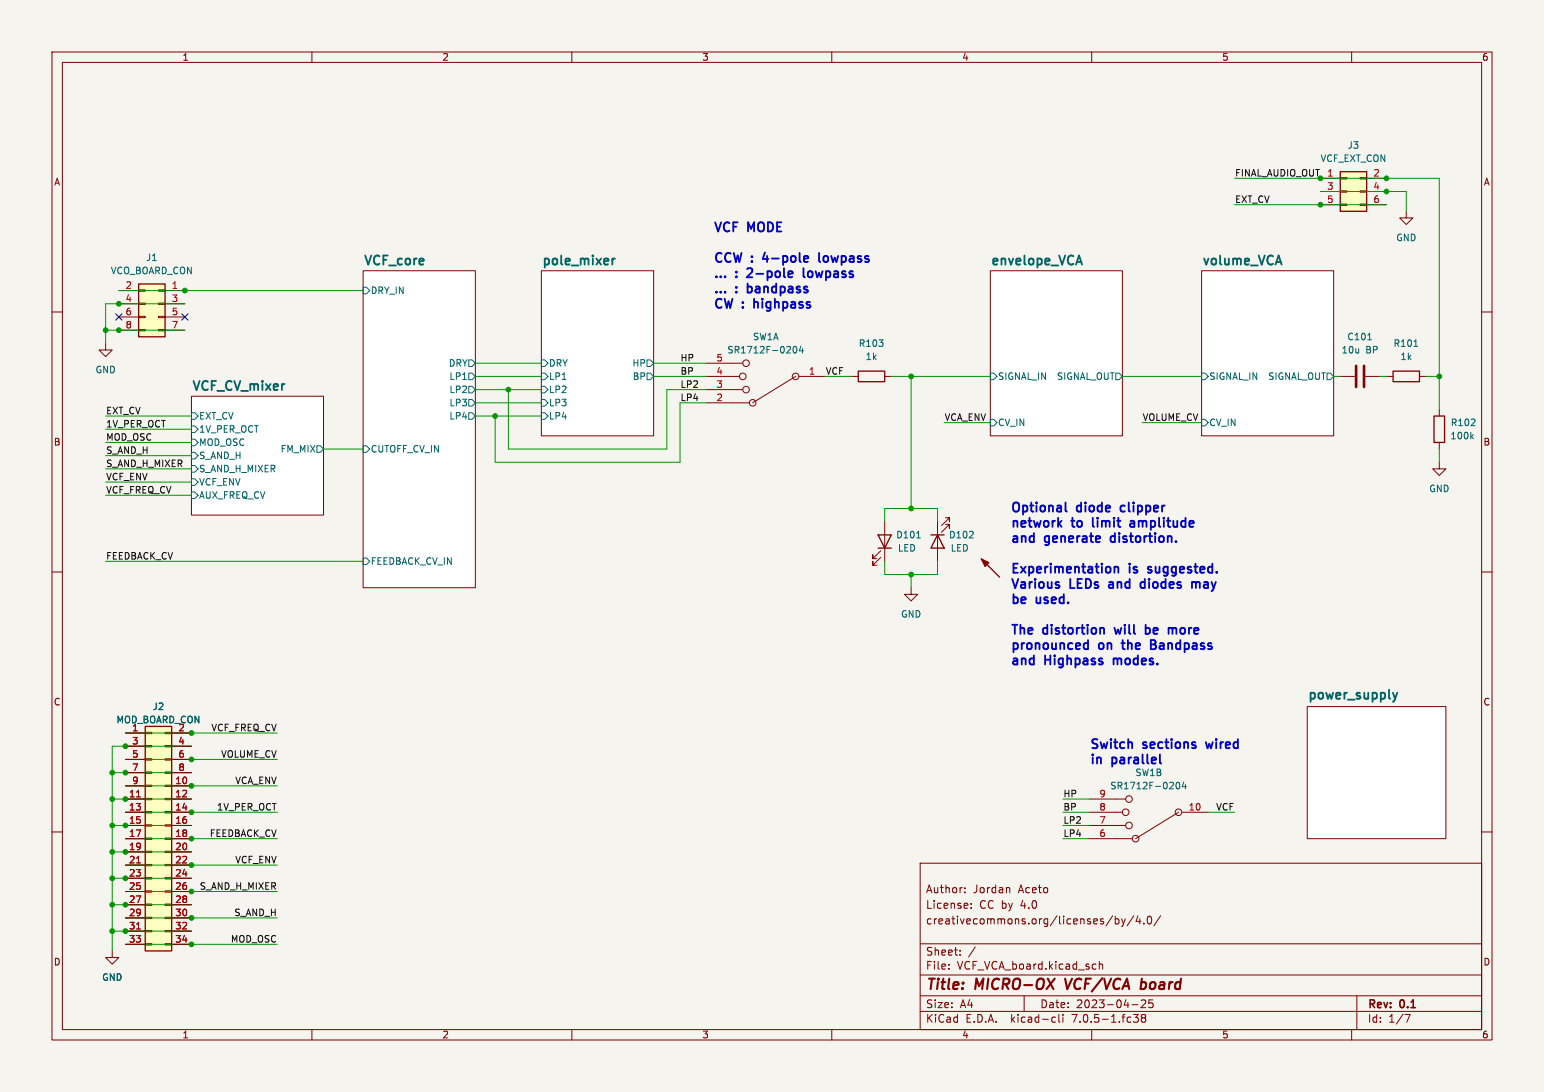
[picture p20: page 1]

Optional diode clipper
network to limit amplitude
and generate distortion.

Various LEDs and diodes may
be used.

The distortion will be more pronounced on the Bandpass

File: VCF_VCA_board.kicad_sch Sheet: / creativecommons.org/licenses/by/4.0/ License: CC by 4.0 Author: Jordan Aceto

Id: 1/7 Title: MICRO-OX VCF/VCA board

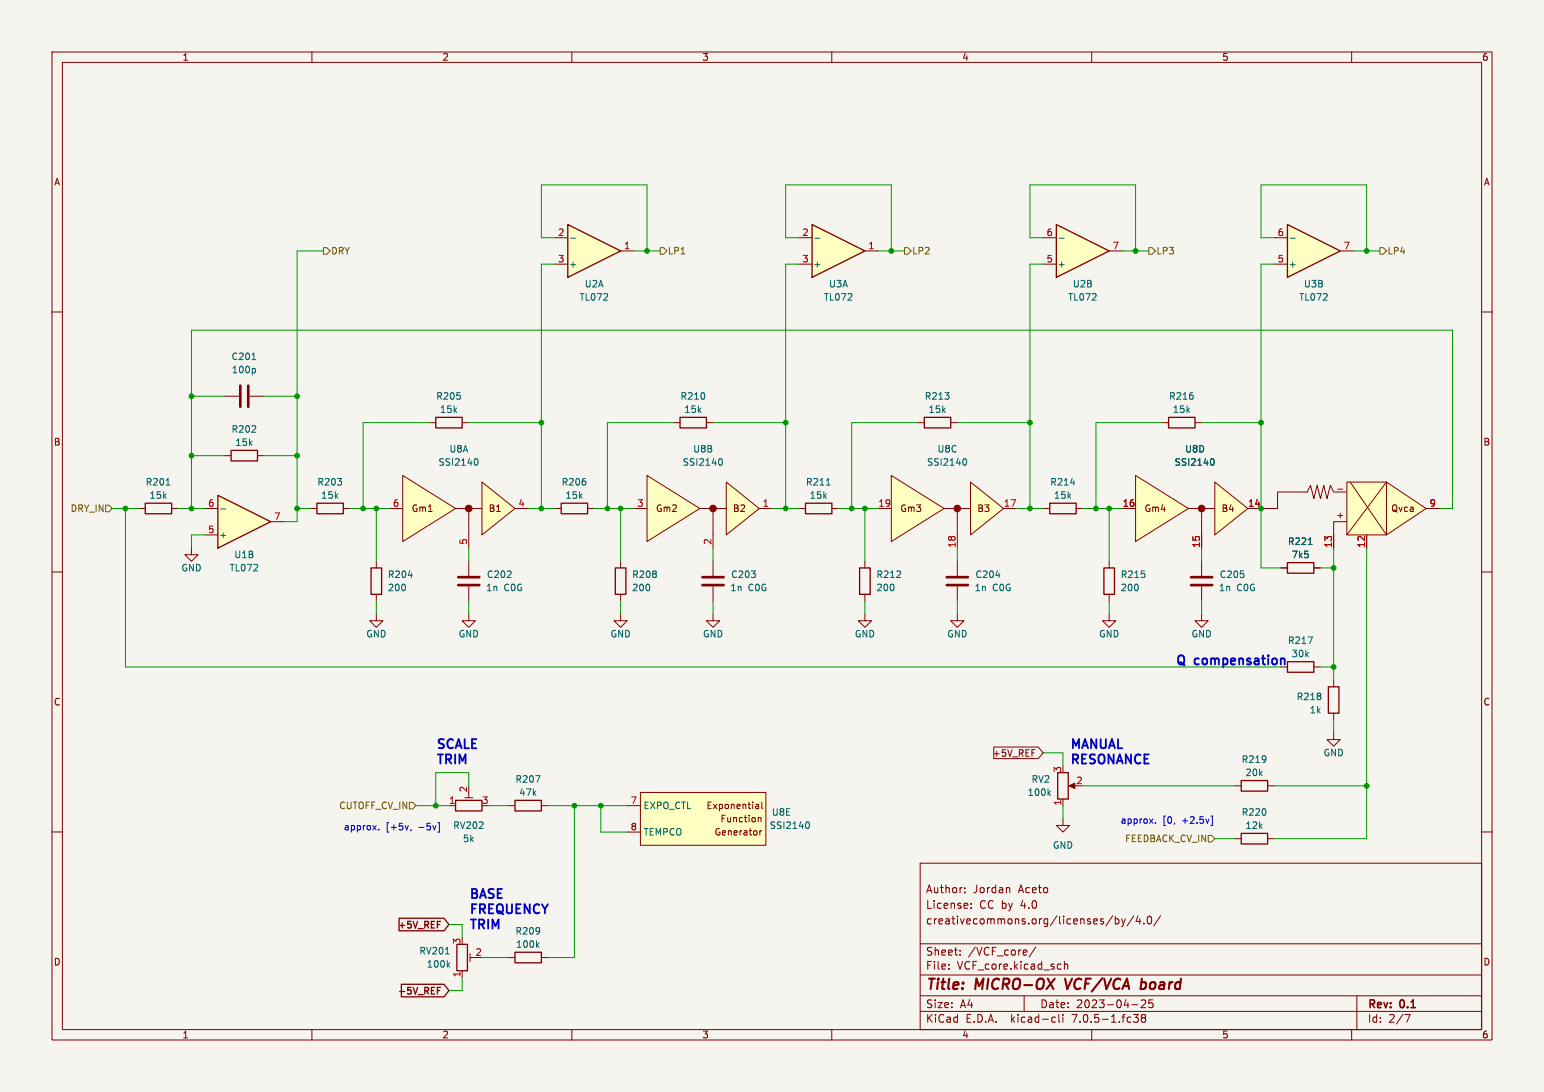
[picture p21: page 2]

creativecommons.org/licenses/by/4.0/ License: CC by 4.0 Author: Jordan Aceto R209

File: VCF_core.kicad_sch Sheet: /VCF_core/
Id: 2/7 Title: MICRO-OX VCF/VCA board

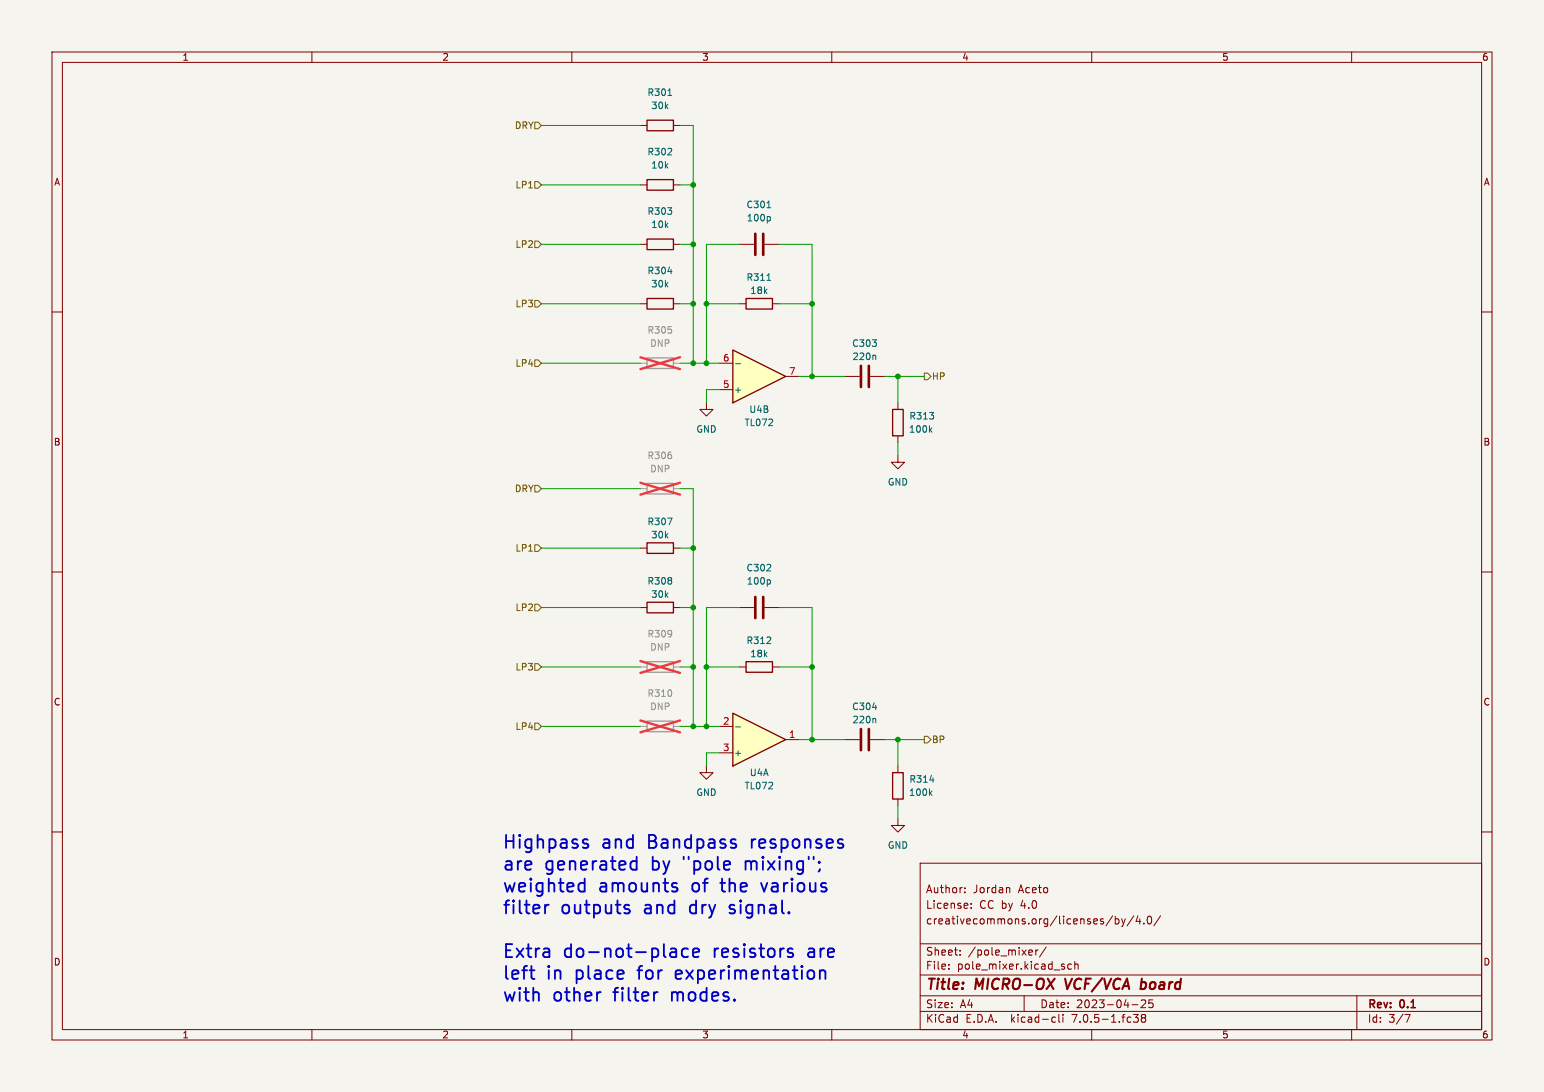
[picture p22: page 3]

File: pole_mixer.kicad_sch Sheet: /pole_mixer/
Id: 3/7 Title: MICRO-OX VCF/VCA board

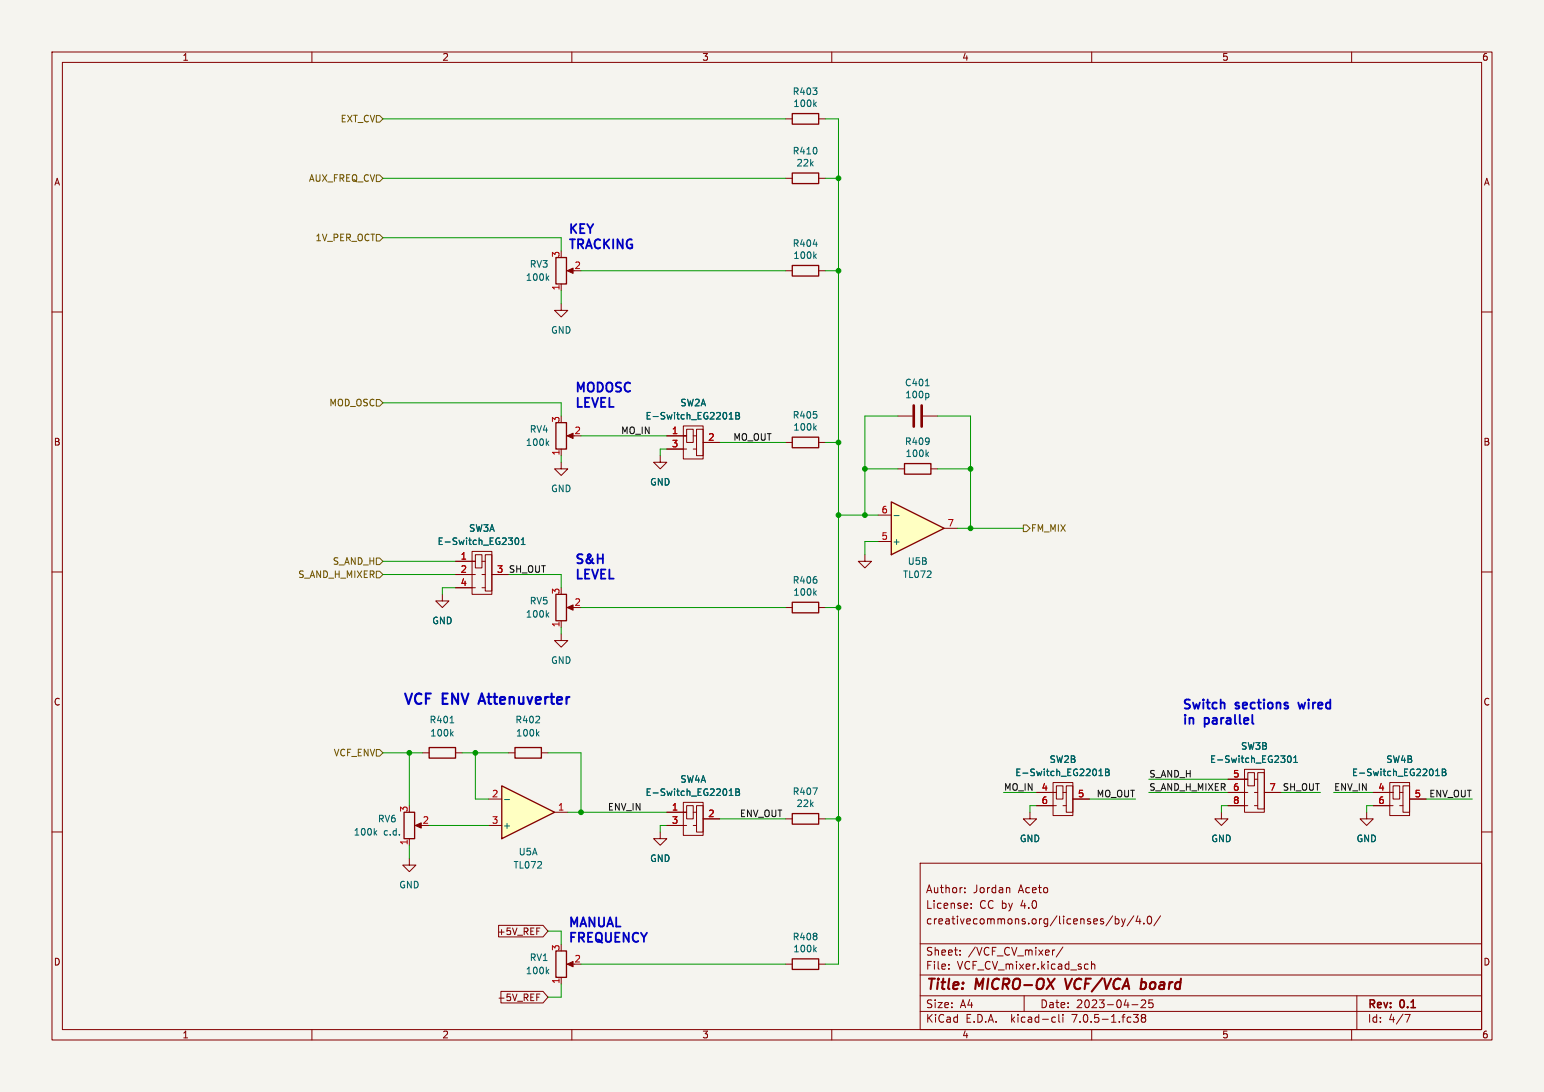
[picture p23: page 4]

creativecommons.org/licenses/by/4.0/ License: CC by 4.0 Author: Jordan Aceto

File: VCF_CV_mixer.kicad_sch Sheet: /VCF_CV_mixer/
Id: 4/7 Title: MICRO-OX VCF/VCA board

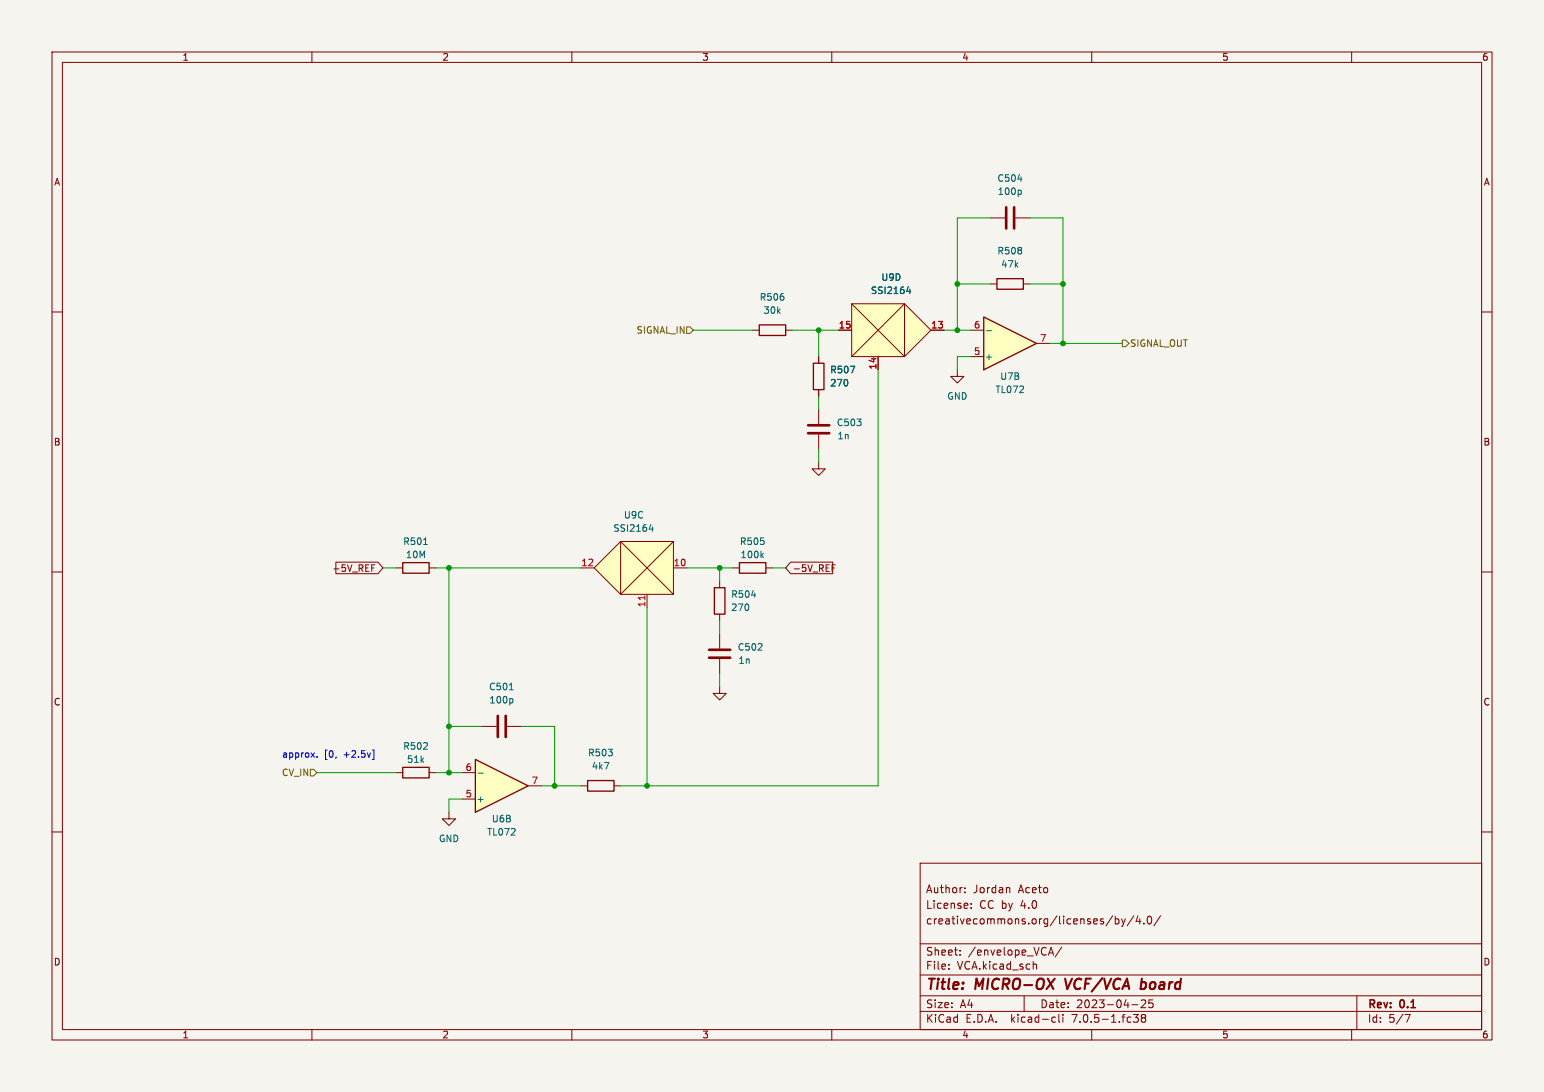
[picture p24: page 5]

creativecommons.org/licenses/by/4.0/ License: CC by 4.0 Author: Jordan Aceto

File: VCA.kicad_sch Sheet: /envelope_VCA/
Id: 5/7 Title: MICRO-OX VCF/VCA board

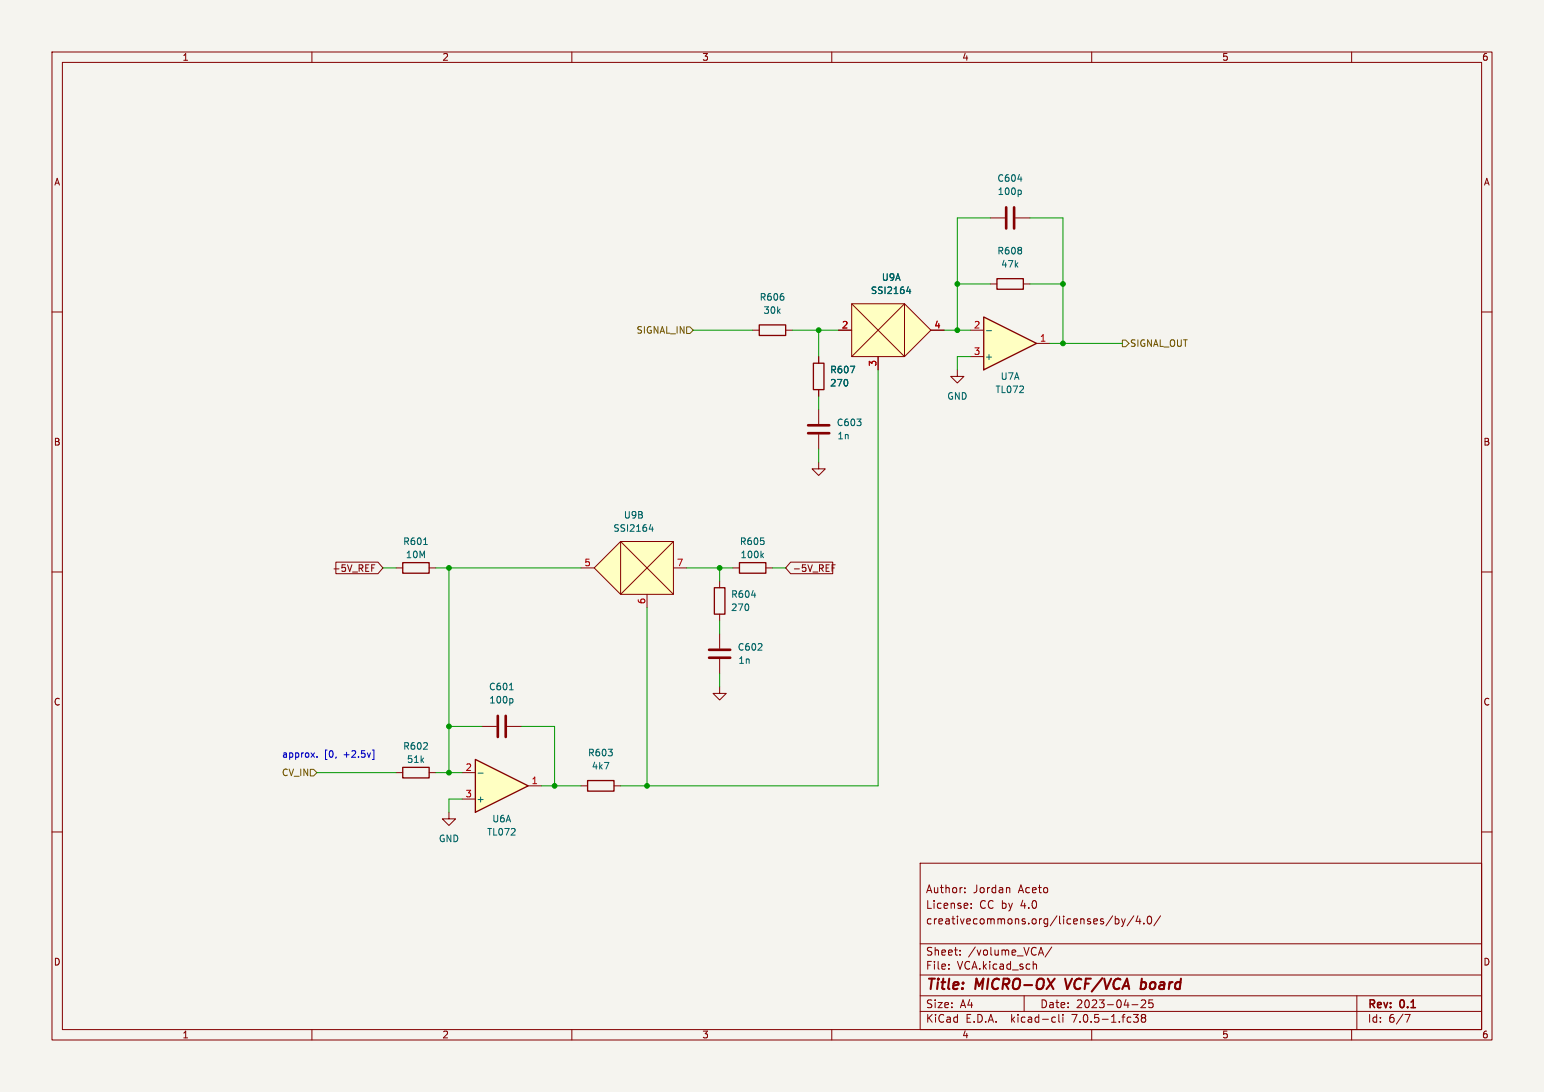
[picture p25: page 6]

creativecommons.org/licenses/by/4.0/ License: CC by 4.0 Author: Jordan Aceto

File: VCA.kicad_sch Sheet: /volume_VCA/
Id: 6/7 Title: MICRO-OX VCF/VCA board

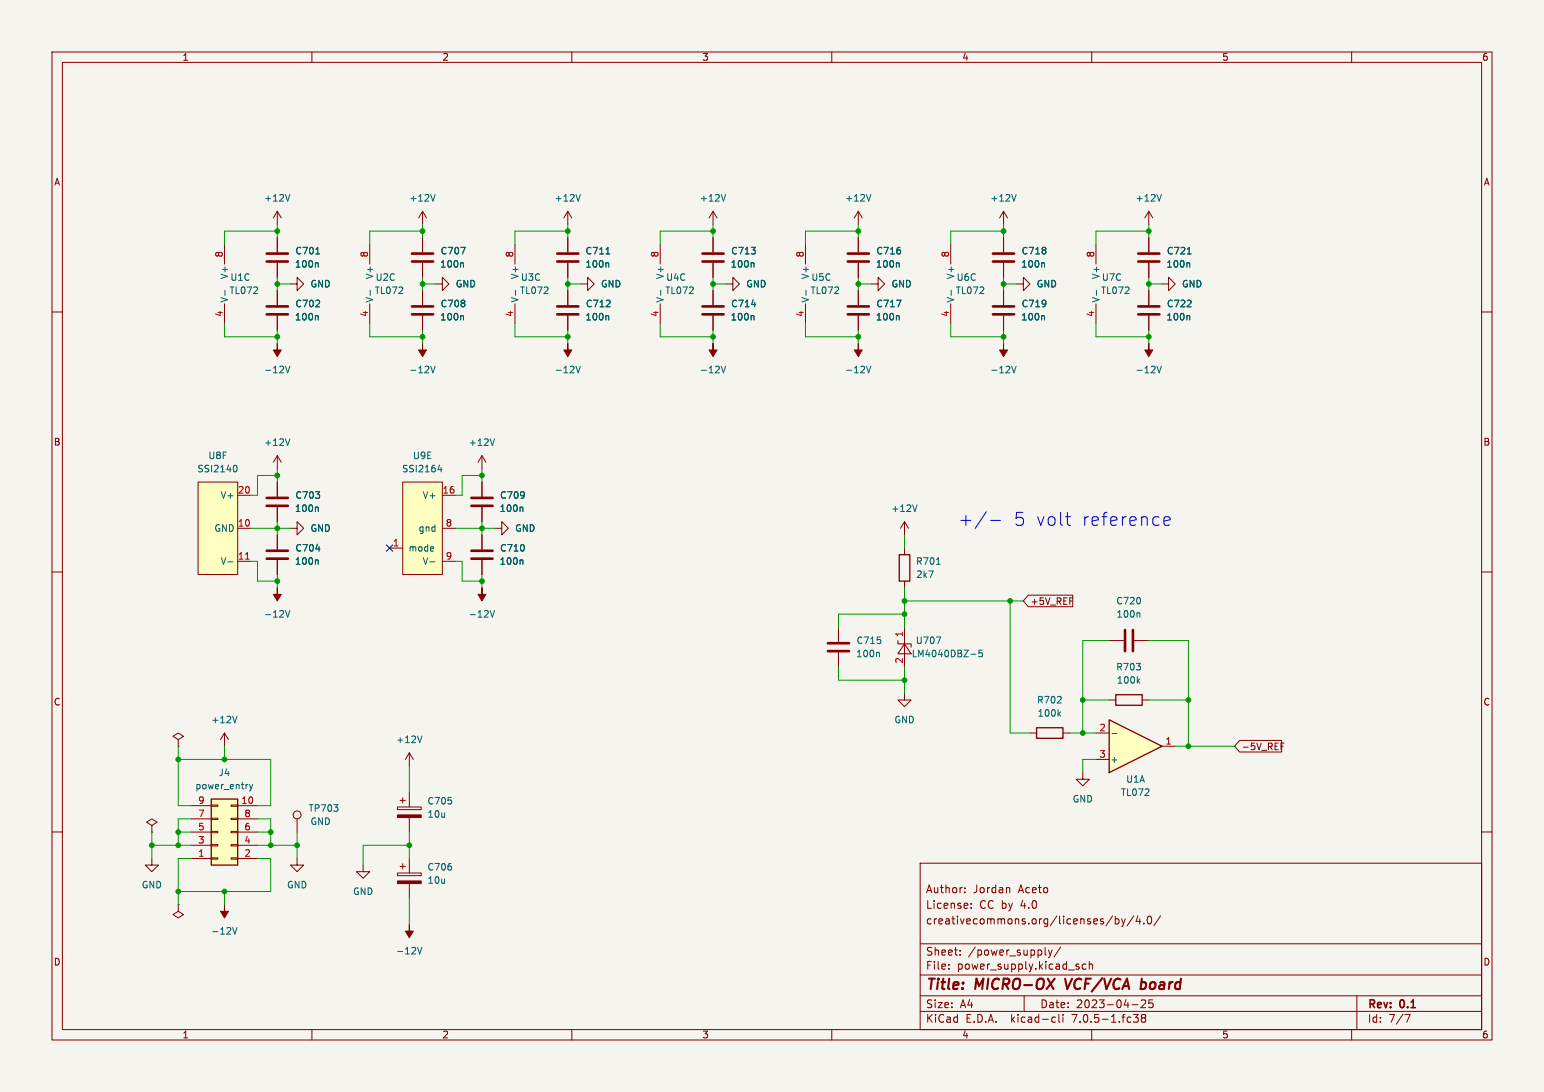
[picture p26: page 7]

creativecommons.org/licenses/by/4.0/ License: CC by 4.0 Author: Jordan Aceto V- 4 V+

File: power_supply.kicad_sch Sheet: /power_supply/
Id: 7/7 Title: MICRO-OX VCF/VCA board

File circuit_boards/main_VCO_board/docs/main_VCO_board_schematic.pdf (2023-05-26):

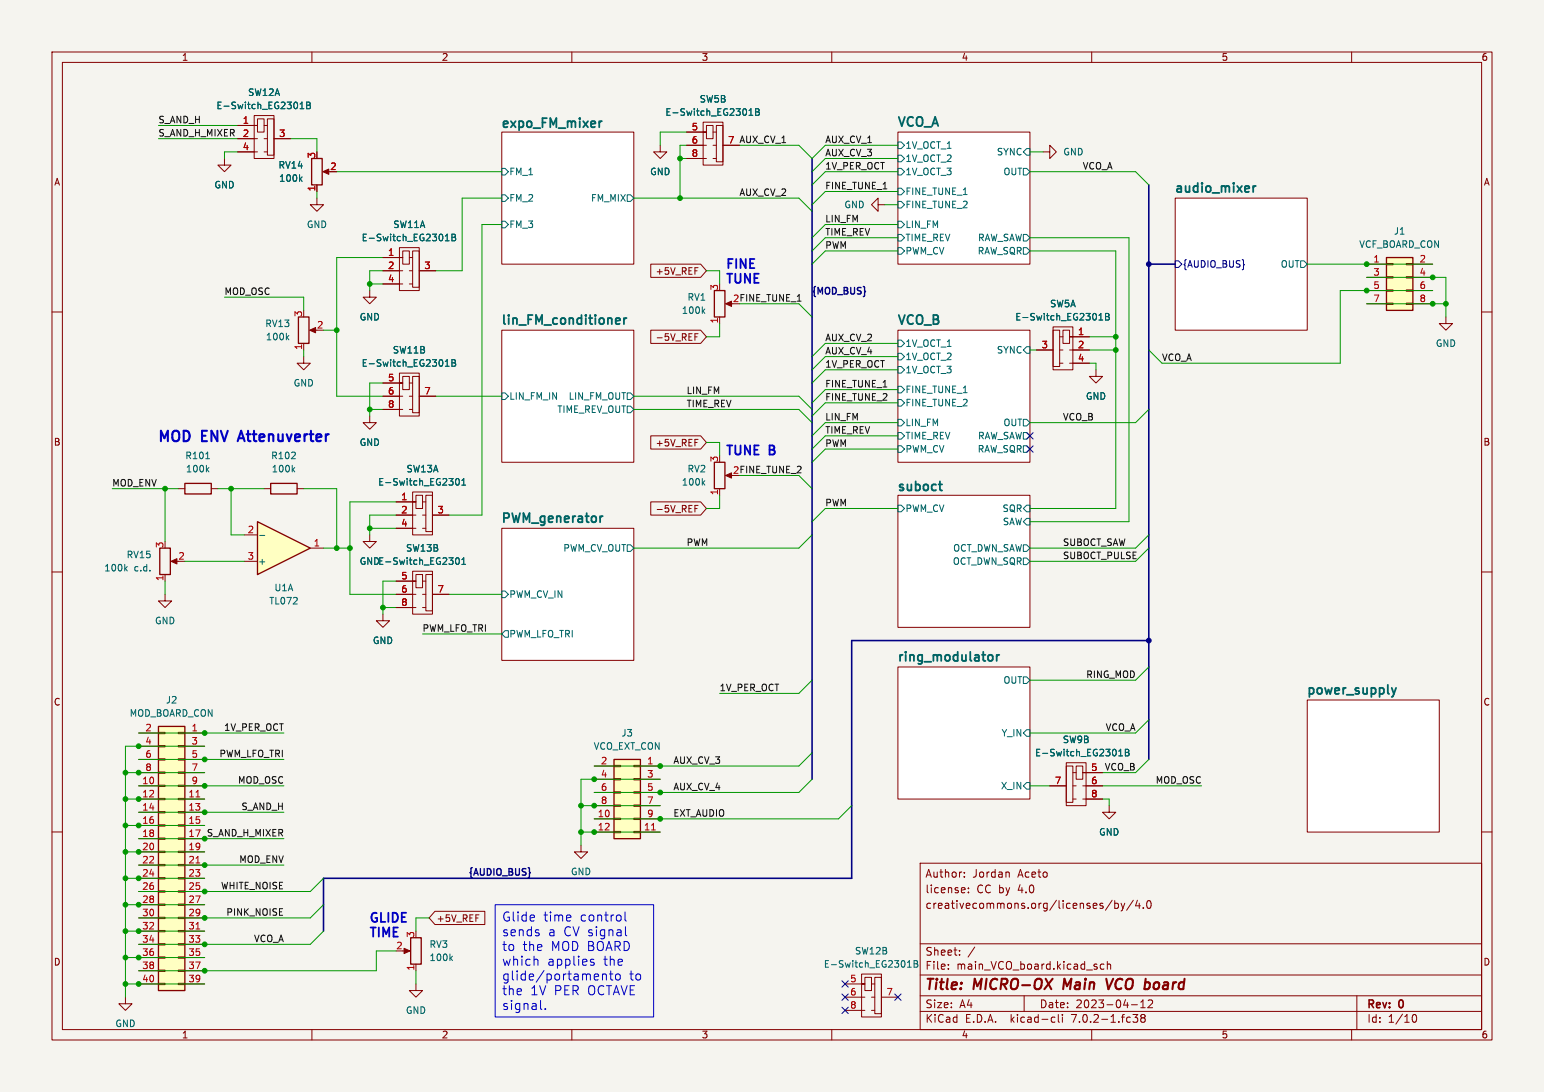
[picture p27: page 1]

File: main_VCO_board.kicad_sch Sheet: / creativecommons.org/licenses/by/4.0

Glide time control
sends a CV signal
to the MOD BOARD
which applies the
the 1V PER OCTAVE
signal.

Id: 1/10 Title: MICRO-OX Main VCO board

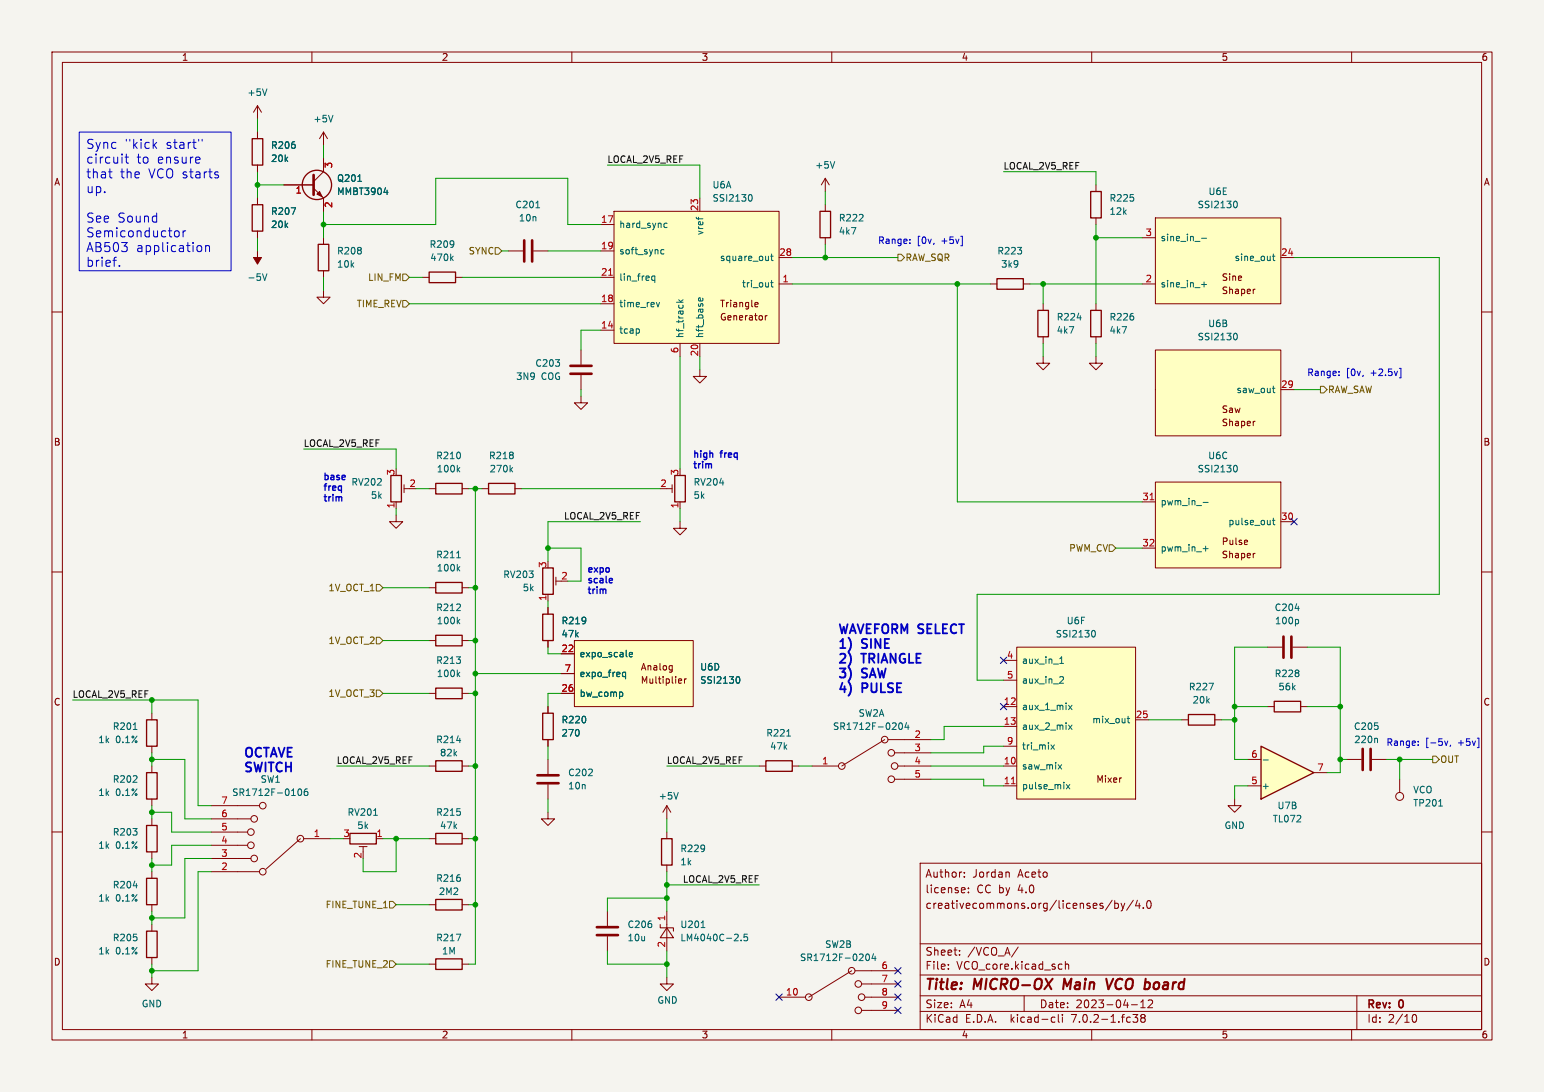
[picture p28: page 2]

Sync "kick start"
circuit to ensure
that the VCO starts

creativecommons.org/licenses/by/4.0

File: VCO_core.kicad_sch Sheet: /VCO_A/
Id: 2/10 Title: MICRO-OX Main VCO board

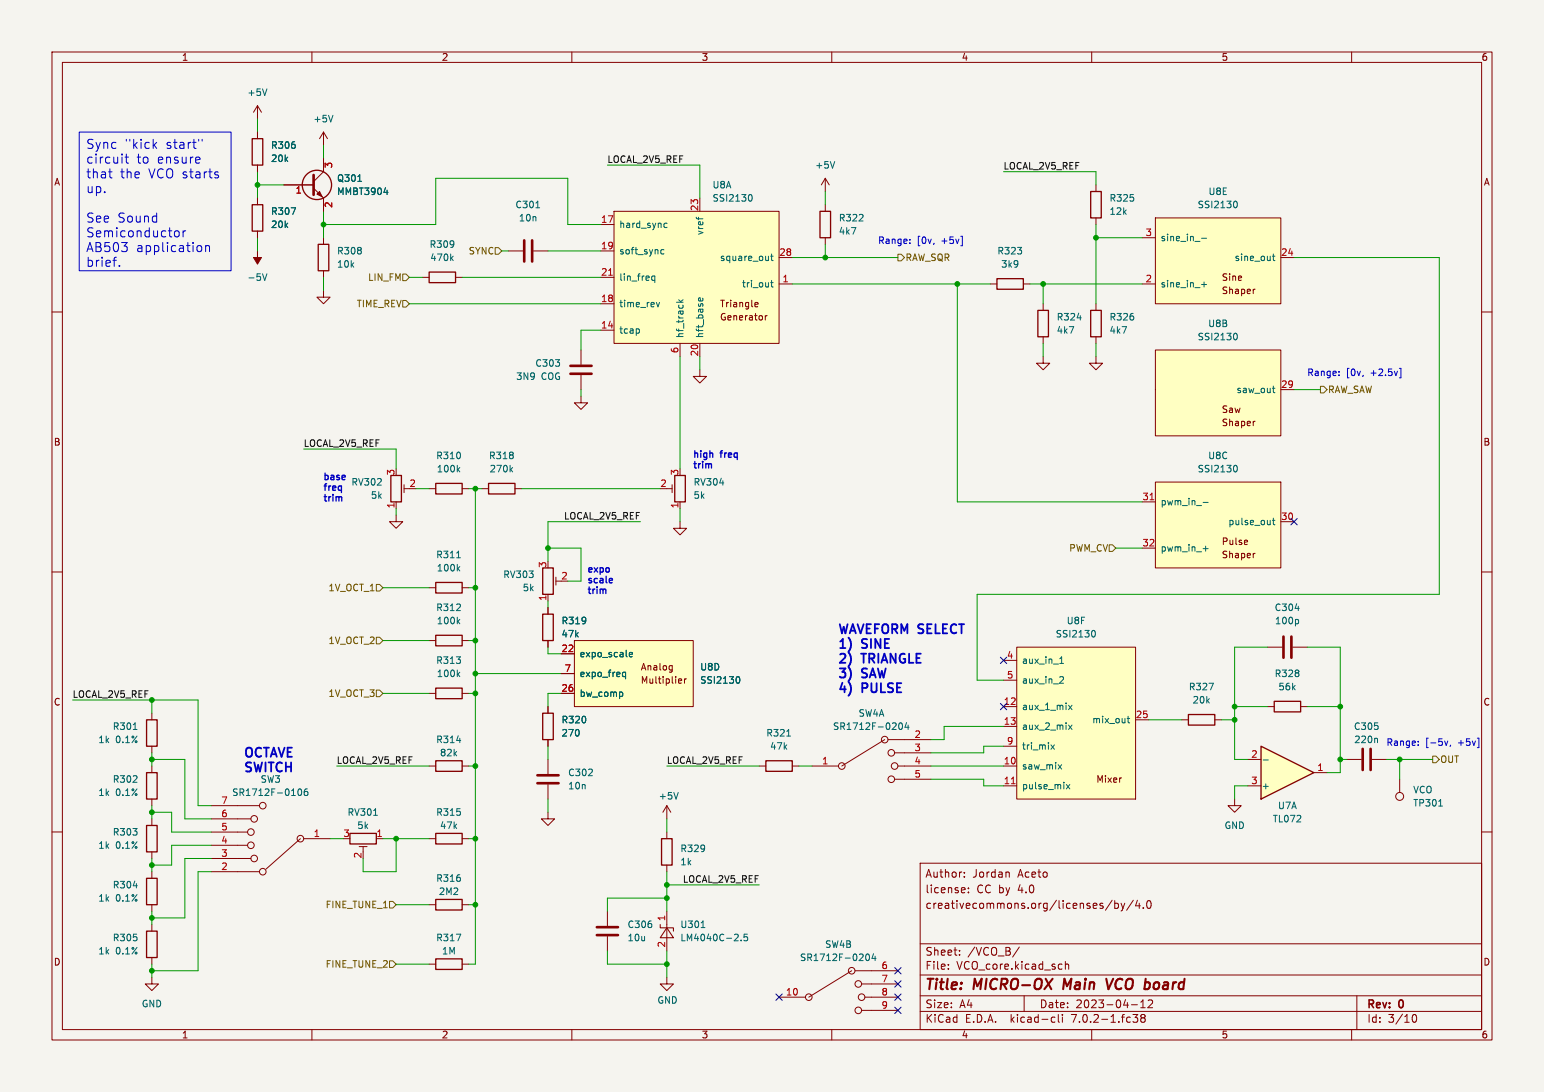
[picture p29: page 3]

Sync "kick start"
circuit to ensure
that the VCO starts

creativecommons.org/licenses/by/4.0

File: VCO_core.kicad_sch Sheet: /VCO_B/
Id: 3/10 Title: MICRO-OX Main VCO board

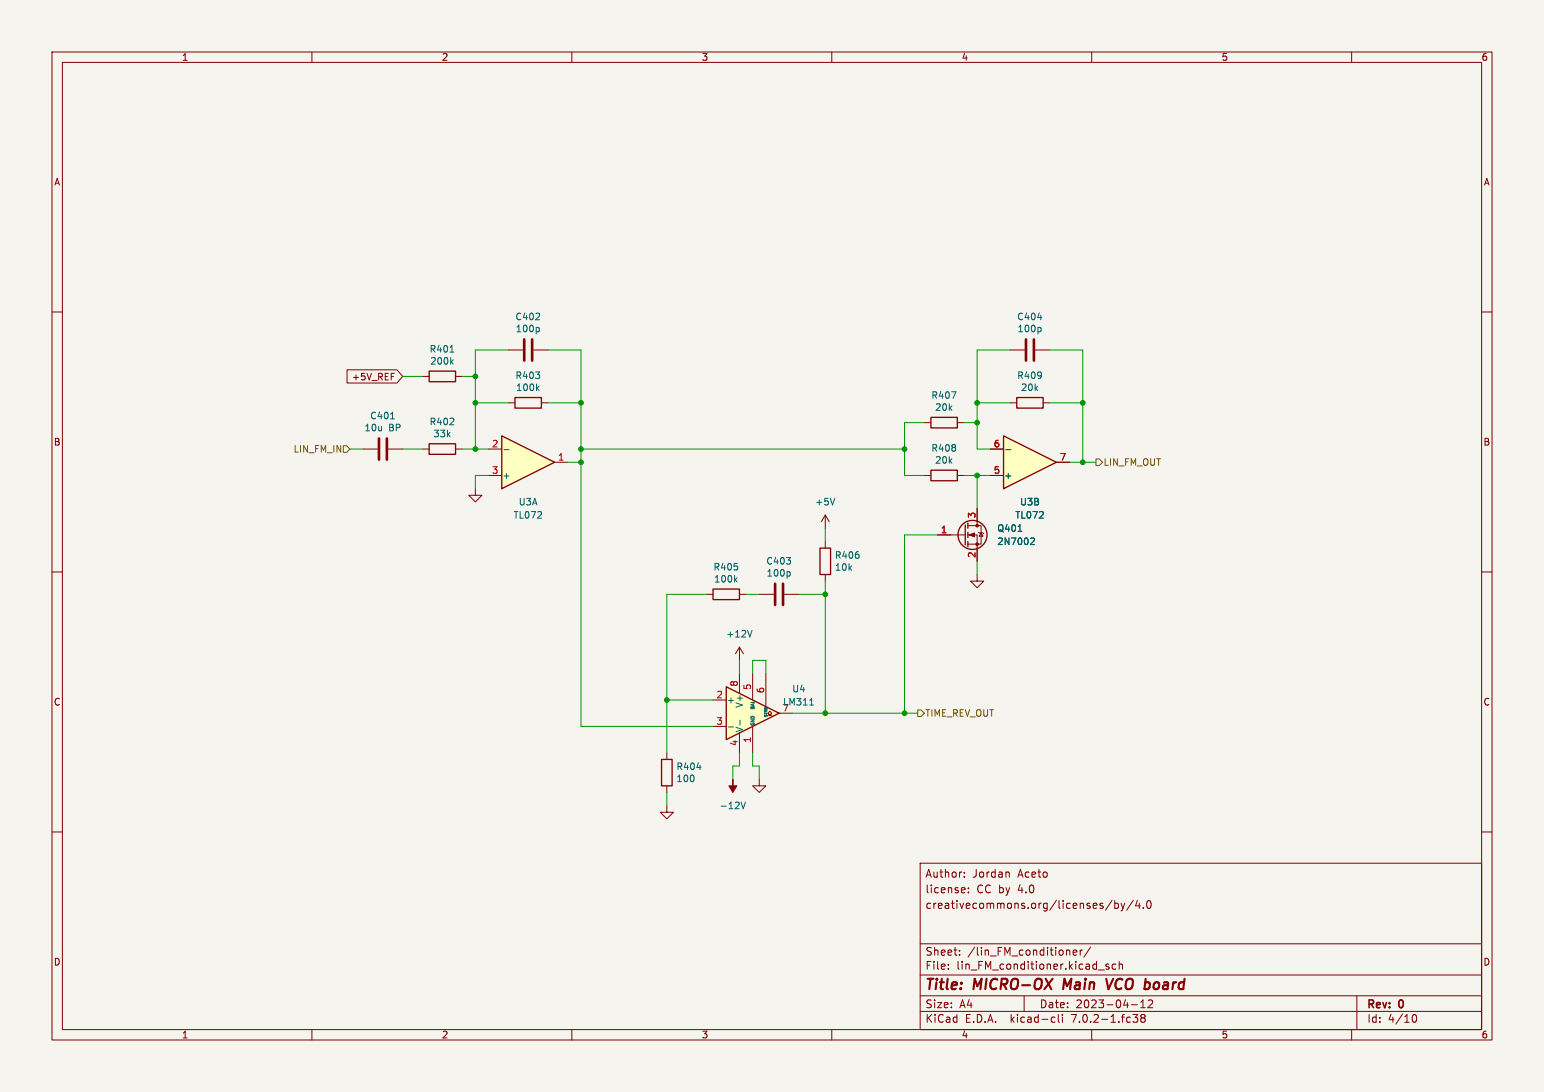
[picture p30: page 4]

creativecommons.org/licenses/by/4.0

File: lin_FM_conditioner.kicad_sch Sheet: /lin_FM_conditioner/
Id: 4/10 Title: MICRO-OX Main VCO board

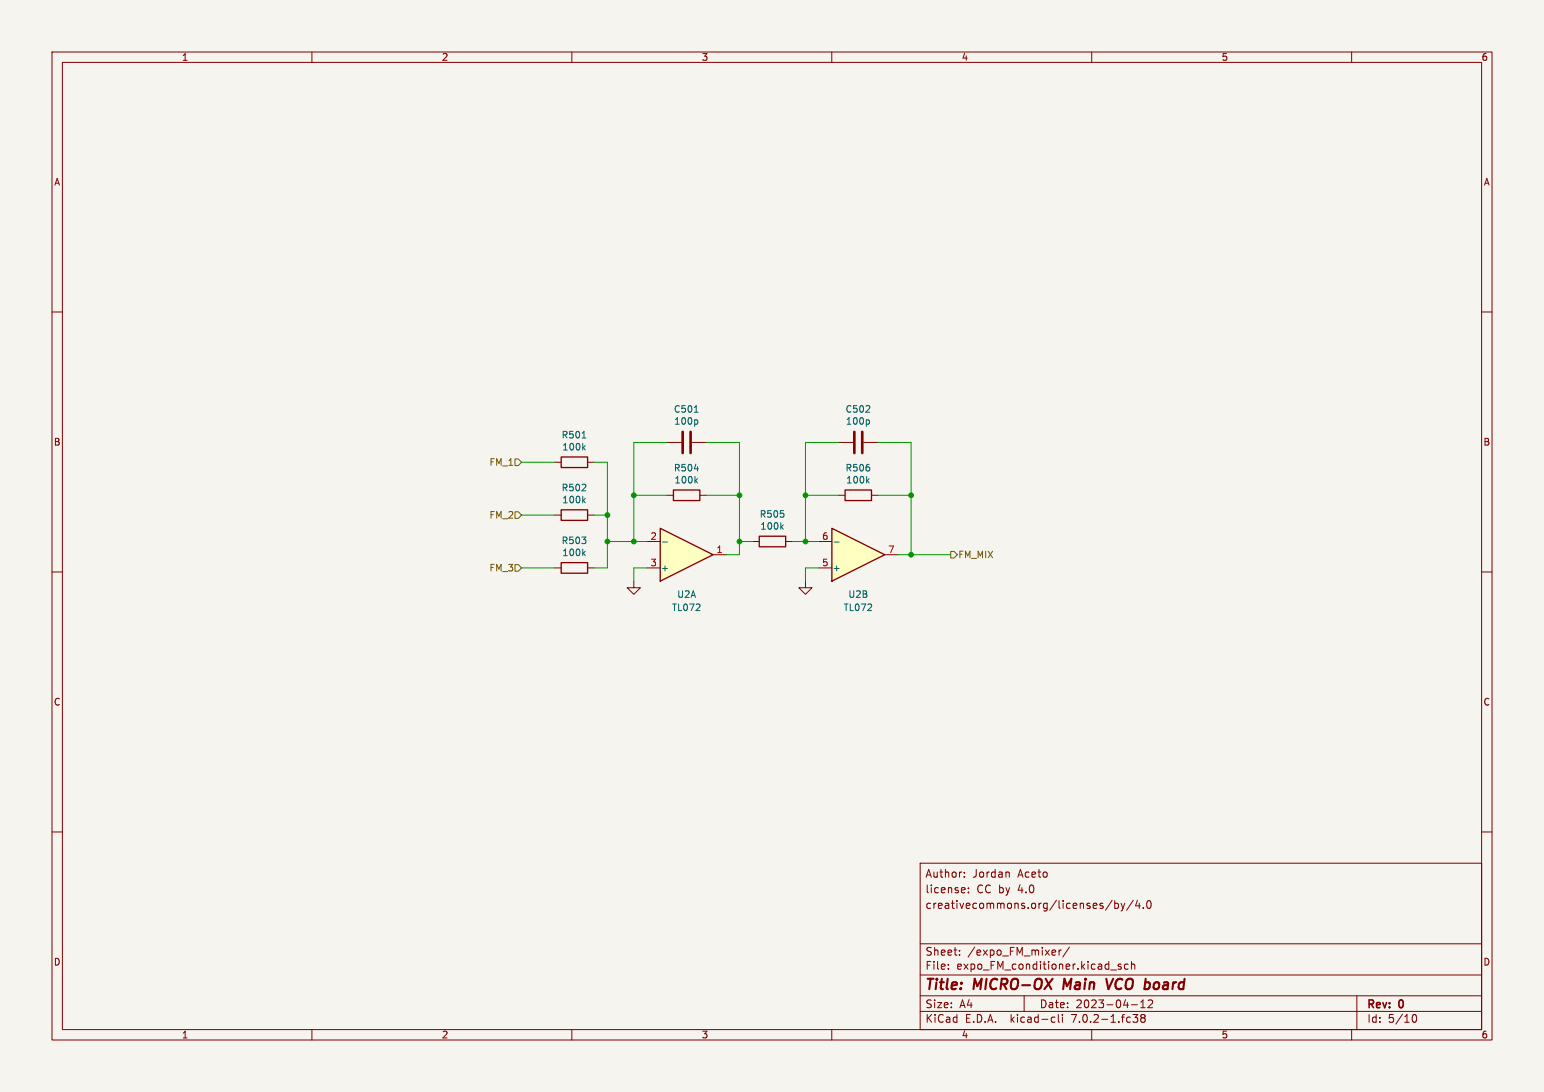
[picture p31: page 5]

creativecommons.org/licenses/by/4.0

File: expo_FM_conditioner.kicad_sch Sheet: /expo_FM_mixer/
Id: 5/10 Title: MICRO-OX Main VCO board


creativecommons.org/licenses/by/4.0

Id: 6/10 Title: MICRO-OX Main VCO board


Saw connect trim. Adjust so that the

slopes at the midpoint of the octave down

glitches from the wave mangling. GND

is used here for its
low slew rate, this
helps to suppress
some of the

Adjust for minimal glitch

at the saw output.

saw animator with suboctave.

File: suboct.kicad_sch Sheet: /suboct/ creativecommons.org/licenses/by/4.0

Id: 7/10 Title: MICRO-OX Main VCO board


creativecommons.org/licenses/by/4.0

File: ring_modulator.kicad_sch Sheet: /ring_modulator/
Id: 8/10 Title: MICRO-OX Main VCO board


creativecommons.org/licenses/by/4.0

File: audio_mixer.kicad_sch Sheet: /audio_mixer/
Id: 9/10 Title: MICRO-OX Main VCO board


creativecommons.org/licenses/by/4.0

Id: 10/10 Title: MICRO-OX Main VCO board

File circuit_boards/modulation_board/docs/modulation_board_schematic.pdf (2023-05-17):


File: modulation_board.kicad_sch Sheet: / creativecommons.org/licenses/by/4.0

Id: 1/10 Title: MICRO-OX Modulation Board


creativecommons.org/licenses/by/4.0

File: digital_ctl_generators.kicad_sch Sheet: /digital_ctl_generators/
Id: 2/10 Title: MICRO-OX Modulation Board


1 PA4 10 PA5 11 PA6 12 PA7 13 PB0 14 PB1 15 VSS 16 VDD 17 PA8 18 PA9 19 PC14 2 PA10 20 PA11 21 PA12 22 PA13 23 PA14 24 PA15 25 PB3 26 PB4 27 PB5 28 PB6 29 PC15 3 PB7 30 PH3 31 NRST 4 VDDA

creativecommons.org/licenses/by/4.0

File: microcontroller.kicad_sch Sheet: /digital_ctl_generators/microcontroller/
Id: 3/10 Title: MICRO-OX Modulation Board


creativecommons.org/licenses/by/4.0

File: analog_controls.kicad_sch Sheet: /digital_ctl_generators/analog_controls/
Id: 4/10 Title: MICRO-OX Modulation Board


creativecommons.org/licenses/by/4.0

File: discrete_controls.kicad_sch Sheet: /digital_ctl_generators/discrete_controls/
Id: 5/10 Title: MICRO-OX Modulation Board


3 ~{LDAC} 4 ~{CLR} 5 ~{SYNC} 6 SCLK 7 DIN 8 AVDD

creativecommons.org/licenses/by/4.0

Id: 6/10 Title: MICRO-OX Modulation Board


S&H trig VCF env trig Auto Gate MOD env trig VCA env trig

The MODOSC on/off
LED is integrated
the DAC

creativecommons.org/licenses/by/4.0

Id: 7/10 Title: MICRO-OX Modulation Board


Pulse is set to
50% duty cycle

creativecommons.org/licenses/by/4.0

File: mod_osc.kicad_sch Sheet: /mod_osc/
Id: 8/10 Title: MICRO-OX Modulation Board


creativecommons.org/licenses/by/4.0

File: s&h_mixer.kicad_sch Sheet: /s&h_mixer/
Id: 9/10 Title: MICRO-OX Modulation Board


creativecommons.org/licenses/by/4.0

Id: 10/10 Title: MICRO-OX Modulation Board

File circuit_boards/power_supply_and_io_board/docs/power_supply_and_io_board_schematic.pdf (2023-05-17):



creativecommons.org/licenses/by/4.0


creativecommons.org/licenses/by/4.0









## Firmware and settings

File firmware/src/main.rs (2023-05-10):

#![no_std]
#![no_main]

mod board;
mod envelopes;
mod gate_routing;
mod modosc_amplitude_ctl;
mod sample_and_hold;
mod ui;

use crate::board::{
    Board, Dac128S085Channel, Dac8162Channel, Led, DAC128S085_MAX_VOUT, DAC8162_MAX_VOUT,
};
use crate::gate_routing::GateSignal;

use synth_utils::{glide_processor, mono_midi_receiver, quantizer};

use panic_halt as _;

use cortex_m_rt::entry;

const DAC_UPDATE_SR: f32 = board::TIM2_FREQ_HZ as f32;

#[entry]
fn main() -> ! {
    let mut board = Board::init();
    let mut ui = ui::Ui::new();
    let mut gate_routing = gate_routing::GateRouting::new();

    let mut midi = mono_midi_receiver::MonoMidiReceiver::new(0);
    let mut midi_glide = glide_processor::GlideProcessor::new(DAC_UPDATE_SR);

    let mut envelopes = envelopes::Envelopes::new(DAC_UPDATE_SR);
    let mut sample_and_hold = sample_and_hold::SampleAndHold::new(DAC_UPDATE_SR);
    let mut sample_and_hold_quantizer = quantizer::Quantizer::new();
    let mut modosc_amplitude_ctl = modosc_amplitude_ctl::ModOscAmplitudeCtl::new(DAC_UPDATE_SR);

    // set some MIDI controls to full-scale to start, this way if nobody plugs in a MIDI controller the volume,
    // mod-wheel ect won't be all the way down. Use running status to do all the CC messages
    for b in [
        /* volume */ 0xB0, 0x07, 127, /* mod wheel */ 0x01, 127,
        /* velocity, no longer in CC running-status, arbitrary note-on with max velocity and then turn the note off again */
        0x90, 0, 127, 0x80, 0, 0,
    ] {
        midi.parse(b)
    }

    loop {
        // handle MIDI input as quickly as possible so we don't miss bytes
        if let Some(byte) = board.read_midi() {
            midi.parse(byte)
        };

        if board.tim2_timeout() {
            board.set_debug_pin(true);

            ui.update(&mut board);

            gate_routing.update(
                board.pwm_lfo_sqr(),
                board.modosc_sqr(),
                midi.gate(),
                board.ext_gate(),
                &mut ui,
            );

            ////////////////////////////////////////////////////////////////////
            //
            // Envelopes
            //
            ////////////////////////////////////////////////////////////////////

            envelopes.update_inputs(&mut ui);

            envelopes.tick(&gate_routing);

            board.dac128S085_set_vout(
                envelopes.vcf_env() * DAC128S085_MAX_VOUT,
                Dac128S085Channel::C,
            );

            board.dac128S085_set_vout(
                envelopes.mod_env() * DAC128S085_MAX_VOUT,
                Dac128S085Channel::E,
            );

            // the VCA can be controlled from a few different signals depending on the front panel switch
            let vca_env = match ui.vca_ctl_mode_switch() {
                ui::VcaCtlMode::ModEnv => envelopes.mod_env(),
                ui::VcaCtlMode::Ar => envelopes.vca_env(),
                ui::VcaCtlMode::Drone => 1.0_f32,
            };
            board.dac128S085_set_vout(vca_env * DAC128S085_MAX_VOUT, Dac128S085Channel::A);

            ////////////////////////////////////////////////////////////////////
            //
            // Sample & Hold
            //
            ////////////////////////////////////////////////////////////////////

            sample_and_hold.set_glide_time(ui.scaled_pot(ui::Potentiometer::SAndHGlide));

            sample_and_hold.tick(
                board.sample_and_hold(),
                gate_routing.state(gate_routing::GateSignal::SAndH),
            );

            // quantize the s&h to force it to play in-tune semitones
            let quantized_s_and_h = sample_and_hold_quantizer
                .convert(sample_and_hold.value() * DAC8162_MAX_VOUT)
                .stairstep;

            board.dac8162_set_vout(quantized_s_and_h, Dac8162Channel::B);

            ////////////////////////////////////////////////////////////////////
            //
            // ModOsc Amplitude Control
            //
            ////////////////////////////////////////////////////////////////////

            modosc_amplitude_ctl.set_glide_time(ui.scaled_pot(ui::Potentiometer::ModOscRiseTime));

            modosc_amplitude_ctl.tick(board.modosc_toggle_switch());

            // the modosc amplitude is controlled by both the front panel on/off switch and MIDI mod-wheel
            board.dac128S085_set_vout(
                modosc_amplitude_ctl.value() * midi.mod_wheel() * board::DAC128S085_MAX_VOUT,
                board::Dac128S085Channel::D,
            );

            ////////////////////////////////////////////////////////////////////
            //
            // MIDI Pitch CV
            //
            ////////////////////////////////////////////////////////////////////

            let midi_1v_per_oct = note_num_to_dac8164_1v_per_oct(midi.note_num());

            midi_glide.set_time(ui.scaled_pot(ui::Potentiometer::Portamento));

            let midi_with_glide = midi_glide.process(midi_1v_per_oct);

            // scale pitch bend for +/- 2 semitones
            let midi_pitch_bend = midi.pitch_bend() * 2.0_f32 / 12.0_f32;

            board.dac8162_set_vout(midi_with_glide + midi_pitch_bend, board::Dac8162Channel::A);

            ////////////////////////////////////////////////////////////////////
            //
            // Misc MIDI controls
            //
            ////////////////////////////////////////////////////////////////////

            board.dac128S085_set_vout(
                midi.vcf_cutoff() * DAC128S085_MAX_VOUT,
                Dac128S085Channel::G,
            );

            board.dac128S085_set_vout(
                midi.vcf_resonance() * DAC128S085_MAX_VOUT,
                Dac128S085Channel::B,
            );

            board.dac128S085_set_vout(midi.volume() * DAC128S085_MAX_VOUT, Dac128S085Channel::H);

            ////////////////////////////////////////////////////////////////////
            //
            // LEDs
            //
            ////////////////////////////////////////////////////////////////////

            board.set_led(Led::SAndHTrig, gate_routing.state(GateSignal::SAndH).into());
            board.set_led(
                Led::VcfEnvTrig,
                gate_routing.state(GateSignal::VcfEnv).into(),
            );
            board.set_led(
                Led::ModEnvTrig,
                gate_routing.state(GateSignal::ModEnv).into(),
            );
            board.set_led(Led::VcaTrig, gate_routing.state(GateSignal::VcaEnv).into());
            board.set_led(
                Led::AutoGate,
                gate_routing.state(GateSignal::AutoGate).into(),
            );

            // the MODOSC LED is driven from an analog voltage to fade in and out
            board.dac128S085_set_vout(
                modosc_amplitude_ctl.led_driver_vout(),
                board::Dac128S085Channel::F,
            );

            board.set_debug_pin(false);
        }
    }
}

/// `note_num_to_dac8164_1v_per_oct(n)` is the note number `n` scaled to 1volt/octave
fn note_num_to_dac8164_1v_per_oct(note_num: u8) -> f32 {
    note_num as f32 / 12.0_f32
}

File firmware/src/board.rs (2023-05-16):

use cortex_m::peripheral::NVIC;

use stm32l4xx_hal::{
    adc::{SampleTime, Sequence, ADC},
    delay::Delay,
    device::{Interrupt, ADC1, DMA1, EXTI, GPIOA, RNG, SPI1, TIM1, TIM15, TIM2, TIM6, USART1},
    gpio::{Alternate, Edge, Floating, Input, Output, Pin, PullUp, PushPull, H8, L8},
    hal::spi::{Mode, Phase, Polarity},
    pac::{interrupt, ADC2},
    prelude::*,
    rcc::{ClockSecuritySystem, CrystalBypass},
    serial,
    spi::Spi,
    timer::Timer,
};

/// The physical board structure is represented here
pub struct Board {
    // USART for MIDI
    _midi_tx: serial::Tx<USART1>,
    midi_rx: serial::Rx<USART1>,

    // onboard multiplexer for reading analog and discrete signals
    mux: Mux,

    // SPI for DACs and LED driver
    spi: SpiBus,

    // general purpose delay
    delay: Delay,

    // binary representation of the LEDs driven by 74HC595 shift register
    led_state: u8,

    // state of the various gate/trigger inputs
    ext_gate_pin: Pin<Input<Floating>, L8, 'A', 7>,
    pwm_lfo_sqr_pin: Pin<Input<Floating>, L8, 'B', 0>,
    modosc_sqr_pin: Pin<Input<Floating>, L8, 'B', 1>,

    // debug pin for misc debug purposes
    debug_pin: Pin<Output<PushPull>, H8, 'A', 12>,
}

impl Board {
    /// `Board::init()` is the board structure with all peripherals initialized.
    pub fn init() -> Self {
        ////////////////////////////////////////////////////////////////////////
        //
        // general peripheral housekeeping, core peripherals and clocks
        //
        ////////////////////////////////////////////////////////////////////////
        let cp = cortex_m::Peripherals::take().unwrap();
        let mut dp = stm32l4xx_hal::pac::Peripherals::take().unwrap();
        let mut flash = dp.FLASH.constrain();
        let mut rcc = dp.RCC.constrain();
        let mut pwr = dp.PWR.constrain(&mut rcc.apb1r1);

        let clocks = rcc
            .cfgr
            .lse(CrystalBypass::Disable, ClockSecuritySystem::Disable) // LSE auto trims the HSI
            .hsi48(true) // needed for RNG
            .sysclk(SYST_CLK_FREQ_MHZ.MHz())
            .pclk1(SYST_CLK_FREQ_MHZ.MHz())
            .pclk2(SYST_CLK_FREQ_MHZ.MHz())
            .freeze(&mut flash.acr, &mut pwr);

        let dma_channels = dp.DMA1.split(&mut rcc.ahb1);

        let mut delay = Delay::new(cp.SYST, clocks);

        let mut gpioa = dp.GPIOA.split(&mut rcc.ahb2);
        let mut gpiob = dp.GPIOB.split(&mut rcc.ahb2);

        ////////////////////////////////////////////////////////////////////////
        //
        // USART
        //
        ////////////////////////////////////////////////////////////////////////

        let tx_pin = gpioa
            .pa9
            .into_alternate(&mut gpioa.moder, &mut gpioa.otyper, &mut gpioa.afrh);
        let rx_pin =
            gpioa
                .pa10
                .into_alternate(&mut gpioa.moder, &mut gpioa.otyper, &mut gpioa.afrh);

        let usart = serial::Serial::usart1(
            dp.USART1,
            (tx_pin, rx_pin),
            serial::Config::default().baudrate(MIDI_BAUD_RATE_HZ.bps()),
            clocks,
            &mut rcc.apb2,
        );
        let (_midi_tx, midi_rx) = usart.split();

        ////////////////////////////////////////////////////////////////////////
        //
        // TIMx periodic timers
        //
        ////////////////////////////////////////////////////////////////////////
        let _tim2 = Timer::tim2(dp.TIM2, TIM2_FREQ_HZ.Hz(), clocks, &mut rcc.apb1r1);

        let _tim6 = Timer::tim6(dp.TIM6, TIM6_FREQ_HZ.Hz(), clocks, &mut rcc.apb1r1);

        let _tim15 = Timer::tim15(dp.TIM15, TIM15_FREQ_HZ.Hz(), clocks, &mut rcc.apb2);

        ////////////////////////////////////////////////////////////////////////
        //
        // ADC1 with DMA to read the sample & hold automatically
        //
        ////////////////////////////////////////////////////////////////////////

        // configure DMA1 to transfer ADC readings to the buffer
        let mut dma1_ch1 = dma_channels.1;
        unsafe {
            dma1_ch1.set_peripheral_address(&dp.ADC1.dr as *const _ as u32, false);
            dma1_ch1.set_memory_address(ADC_DMA_BUFF.as_ptr() as u32, true);
        }
        dma1_ch1.set_transfer_length(NUM_ADC_DMA_SIGNALS as u16);
        unsafe {
            (*DMA1::ptr()).ccr1.modify(|_, w| {
                w.msize()
                    .bits16()
                    .psize()
                    .bits16()
                    .minc()
                    .enabled()
                    .circ()
                    .enabled()
                    .en()
                    .set_bit()
            });
        }

        let mut adc1 = ADC::new(
            dp.ADC1,
            dp.ADC_COMMON,
            &mut rcc.ahb2,
            &mut rcc.ccipr,
            &mut delay,
        );
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

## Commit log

2023-04-15 Progress on circuit boards
    [5511MBLKxxx.stp, DAC.kicad_sch, LED_driver.kicad_sch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]
2023-04-17 Begin firmware, start board module
2023-04-17 Tweaks to mod board, add debug pin
    [DAC.kicad_sch, LED_driver.kicad_sch, analog_controls.kicad_sch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]
2023-04-17 Tweaks to front panel, fix some copy-paste errors
    [micro_ox_front_panel.kicad_pcb]
2023-04-19 Tweaks to mod board, add debug pin, move SPI CS
    [analog_controls.kicad_sch, discrete_controls.kicad_sch, microcontroller.kicad_sch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]
2023-04-20 Tweaks to mod board, debounce MODOSC toggle switch
    [DAC.kicad_sch, LED_driver.kicad_sch, analog_controls.kicad_sch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]
2023-04-21 Swap some pins on MOD board for independent EXTI lines
    [DAC.kicad_sch, LED_driver.kicad_sch, analog_controls.kicad_sch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]
2023-04-21 Firmware progress, add UI, Gate Routing, and Envelopes modules, tweak board
2023-04-25 Update PCBs, tweak vals, add VCF CV from DAC
    [DAC.kicad_sch, LED_driver.kicad_sch, PWM_generator.kicad_sch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]
2023-04-25 Update front panel
    [micro_ox_front_panel.kicad_pcb, micro_ox_front_panel.kicad_sch]
2023-04-25 Add instructions for VCO board PCB kludge
2023-05-03 Tweaks to VCO R values
    [audio_mixer.kicad_sch, suboct.kicad_sch]
2023-05-07 Swap mixed up vcf/vca env signals
    [DAC.kicad_sch, microcontroller.kicad_sch, modulation_board.kicad_pcb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]
2023-05-07 Fix bug with VCF env gate
    [gate_routing.rs]
2023-05-07 Fix copy-paste error in DAC schematic symbol
    [DAC.kicad_sch, analog_controls.kicad_sch, microcontroller.kicad_sch]
2023-05-07 Turn sample and hold back on after testing
2023-05-07 Update main app, add MIDI pitch CV
2023-05-08 Fix bug where first round-robbin ui signal was not updated
    [ui.rs]
2023-05-08 Underscore currently unused code to pass clippy
2023-05-10 Quantize sample&hold
2023-05-10 Tweaks, invert PWM LFO clk, init MODOSC to ON, raise sample rate
    [board.rs]
2023-05-10 Resistor tweaks while evaluating 1st build
    [LED_driver.kicad_sch, PWM_generator.kicad_sch, VCF_VCA_board.kicad_pcb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]
2023-05-10 Add modulation board PCB kludges instructions
2023-05-10 Increase VCF 1v/oct drive so it can be trimmed to play in tune
    [VCF_VCA_board.kicad_pcb, VCF_core.kicad_sch]
2023-05-11 Increase range of VCO B fine tune control
    [VCO_core.kicad_sch, main_VCO_board.kicad_sch]
2023-05-11 Fix typo in note about clipping diodes
    [VCF_VCA_board.kicad_sch]
2023-05-11 Add instructions for VCO octave switch buffer kludge
2023-05-14 Add power supply/IO board KiCad project
    [5511MBLKxxx.stp, 57PC5F.STEP, ALPHA-RD901F-40.step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]
2023-05-14 Add basic README for power-supply/IO board
2023-05-16 Fix comment with wrong polarity for switch signals
    [board.rs]
2023-05-17 Fix copy paste error with SSI2140 symbol, add potentiometer 3d model
    [VCF_CV_mixer.kicad_sch, VCF_VCA_board.kicad_pcb, VCF_core.kicad_sch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]
2023-05-17 Add potentiometer 3d model to VCO and MOD boards
    [ALPHA-RD901F-40.step, DAC.kicad_sch, PWM_generator.kicad_sch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]
2023-05-17 Update PCB level READMEs with description of features
2023-05-17 Add PCB docs for first round of prototypes
    [VCF_VCA_board_bom.csv, main_VCO_board_bom.csv, modulation_board_bom.csv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]
2023-05-17 Update power supply/IO board README with correct schem link and SVGs
2023-05-17 Add README to top of circuit_boards directory
2023-05-17 Add note about pcb kludges to circuit boards level README
2023-05-18 Reduce bandpass gain
    [VCF_VCA_board.kicad_pcb, VCF_VCA_board_bom.csv, pole_mixer.kicad_sch]
2023-05-20 Turn down bandpass gain even more
    [VCF_VCA_board.kicad_pcb, VCF_VCA_board_bom.csv, pole_mixer.kicad_sch]
2023-05-26 Fix bug where animator LFO would rail out
    [lin_FM_conditioner.kicad_sch, main_VCO_board.kicad_sch, main_VCO_board_bom.csv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]
2023-06-18 Increase gain for hotter output
    [VCA.kicad_sch, VCF_VCA_board.kicad_pcb, VCF_VCA_board_bom.csv]
2023-06-18 Tone down Q-compensation to avoid volume increase with high Q
    [VCF_VCA_board.kicad_pcb, VCF_VCA_board_bom.csv, VCF_core.kicad_sch]
2023-06-18 Add image of completed prototype, show image in main README
2023-06-18 Add jack-panel KiCad project, add docs for front panel and jack panel
    [jack_panel.kicad_pcb, jack_panel.kicad_sch, jack_panel.step]

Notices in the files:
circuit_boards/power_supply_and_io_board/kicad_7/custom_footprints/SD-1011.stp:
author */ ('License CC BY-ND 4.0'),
